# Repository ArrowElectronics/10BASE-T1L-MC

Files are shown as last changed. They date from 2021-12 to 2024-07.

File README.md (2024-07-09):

# 10BASE-T1L-MC: 10BASE-T1L to 10BASE-T Media Converter Platform 

This repository is dedicated to the 10BASE-T1L Media Converter including the source code, HW package files for Development, User Guides. 

The media converter (“10BASE-T1L-MC”) is a plug and play solution which enables seamlessly interfacing from single twisted pair (SPE) long reach Industrial Ethernet (“10BASET1L”)
to standard Ethernet (“10BASE-T”).

The 10BASE-T1L-MC is built using the industry leading PHY technology from Analog Devices ADI Chronous Family, namely the ADIN1100, 10BASE-T1L PHY and the ADIN1200, 10BASE-T PHY.

## 10BASE-T1L Software Package

The software package includes the configuration of both the PHY ADIN1100 and ADIN1200 with the MAX32660 MCU.

- Both the PHYs are configured with MCU over MDIO Interface GPIO Bit Banging.
- The PHYs has been programmmed to configure it in auto-negotiation, full-duplex mode, and speed at 10 Mbps. 
- The Device is programmmed with LED indication in case of various events like Power LED of MCU, Link Status LED and Activity Status LED for ADIN1100 and ADIN1200.  
- Debug UART hase been programmmed to show logs for Board Info and PHYs configuration status. 

## 10BASE-T1L Hardware Package

Hardware Package of 10BASE-T1L-MC contains Architectural Level Block Diagram, Gerber, BoM, Schematics for the development purpose, Pre-Scan Reports.

## 10BASE-T1L Mechanical Package

Mechanical Packages inlcudes CAD Data, Mechanical BoM, Mechanical Drawing, Packaging Instructions.

# Terms of Sale

Please refer to e-Infochips Private Limited Terms and Conditions of Sale found [here](https://uat.arrow.com/en/legal/terms-and-conditions-of-sale)

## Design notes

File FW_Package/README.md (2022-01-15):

# SW Pakcgage

The firmware released is of the Beta phase, it includes the development of ADIN1100 and ADIN1200 drivers, 
enabling the MDIO interface through GPIO Bit Banging, also the UART debugging through the debug console for the MCU Info, ADIN1100 and ADIN1200 debug log. 

## Software Tools Used

**Software Used**: [ ECLIPSE MAXIMSDK ](https://www.maximintegrated.com/en/design/software-description.html/swpart=SFW0010820A)<br/>
**Hardware Used**: Programming Cable (TC2030-IDC) and Programming Adapter – (MAX32625PICO#)

## Installation Notes

The installation manual followed for the development is as per the Programming Guide given for MAX32660 EVM Kit [(Programming_32660)](Programming_32660.pdf)  and following are the steps to be followed for debugging the device: 

1)	To open the given AIT1L project: page 14-19 in the above-mentioned document
2)	To build the project: Refer Page no. 6-7
3)	To debug the project: Refer Page no. 7-10
4)	To launch the UART debug console in serial terminal: 11-14

**Another way for flashing 10BASE-T1L without entering debugging mode:**

Tool used for flashing of device is Arm Toolchain and OpenOCD used to connect microcontrollers for debugging purpose. 

 To begin using OpenOCD, launch a command prompt window and change the directory to the location containing the application files you want to load. Load the file by running the following command line: 

[install_path]\Toolchain\bin\openocd -s [install_path]\Toolchain\share\openocd\scripts -f interface\[adapter].cfg -f target\[device].cfg -c "program [elf_file] verify exit"

Replace the parameters in [brackets] to match your configuration.
- [install_path]- This path where you installed the ARM toolchain. The default installation path is C:\Maxim
- [adapter] - The JTAG or SWD adapter connected to your board. In this case replace [adapter] --> cmsis-dap
- [device] - replace this with max32660
- [elf_file] - 10BASE-T1L-MC_B.elf

Command executed at development end:

C:\MaximTool\Toolchain\bin\openocd -s C:\MaximTool\Toolchain\share\openocd\scripts -f interface\cmsis-dap.cfg -f target\max32660.cfg -c "program AIT1L.elf verify exit" 

Note: Please follow the above replacements based on the installation path and project path at the individual end. 

Figure 8 shows an example for loading an AIT1L.elf to the device.

**Note**: Please follow the above replacements based on the installation path and project path at the individual end. 

Figure 8 shows an example for loading an AIT1L.elf to the device. 

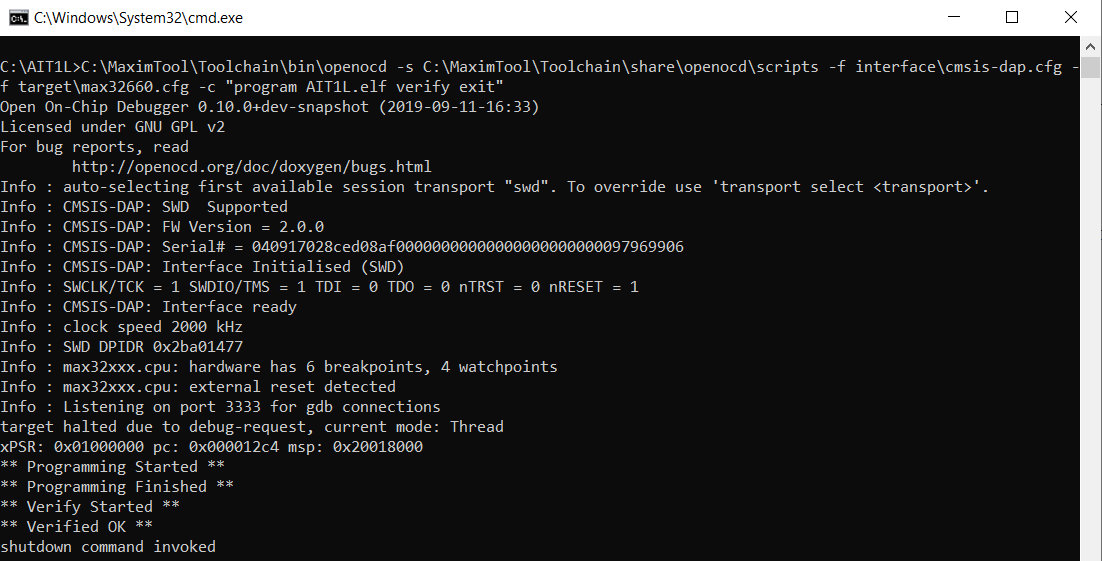
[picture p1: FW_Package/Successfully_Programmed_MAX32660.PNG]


Reference Web Link for Downloading the Software and all the steps for loading the program is shown below:

•	[How to Load Application to Maxim’s MAX32660 MCU](https://www.maximintegrated.com/en/design/technical-documents/app-notes/6/6973.html).

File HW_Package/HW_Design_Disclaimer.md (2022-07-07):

**DISCLAIMER**: THIS CIRCUIT DESIGN IS A PROVIDED AS REFERENCE ONLY, WITHOUT WARRANTY EXPRESSED OR IMPLIED.
THE USER IS ENCOURAGED TO PERFORM ALL DUE DILIGENCE WITH RESPECT TO DESIGN AND ANALYSIS.
FOR COMMITTED PERFORMANCE AND FUNCTIONALITY OF THE DEVICE, PLEASE REFER TO THE DEVICE DATA MANUAL

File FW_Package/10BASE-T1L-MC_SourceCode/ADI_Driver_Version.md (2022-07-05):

## ADIN1110 Driver (Non-OS) version information:

The ADIN1100 driver used at the time of development of 10BASE-T1L-MC is **adin1100_v1.0.0**.

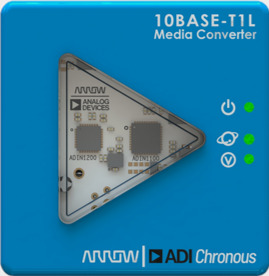
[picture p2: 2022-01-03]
Wiki_Page_Images/10BASE-T1L-MC.png

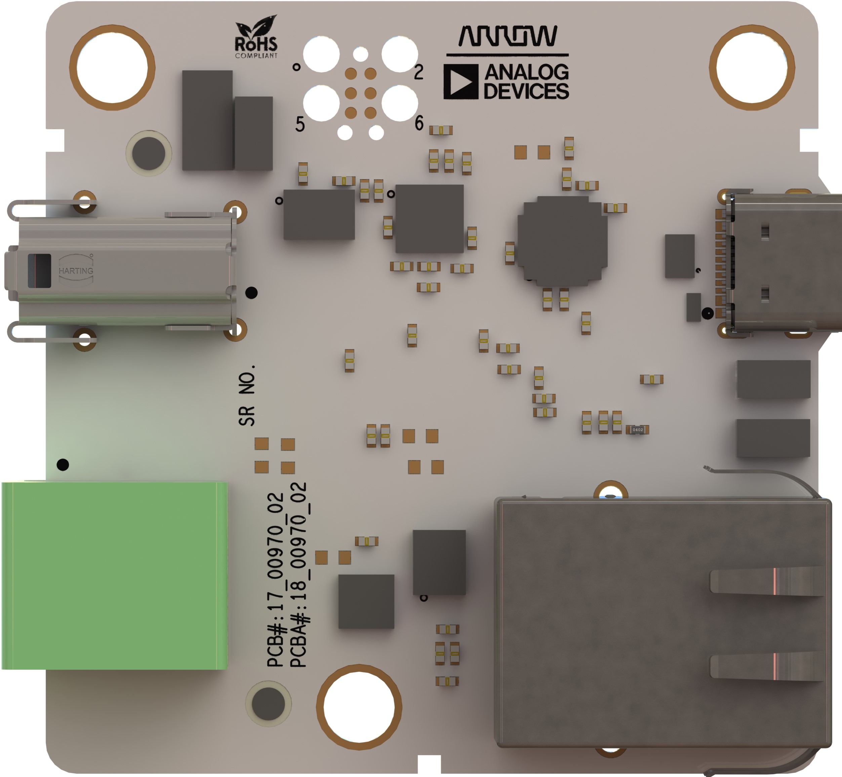
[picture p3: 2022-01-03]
Wiki_Page_Images/PCBA_FrontView.JPG

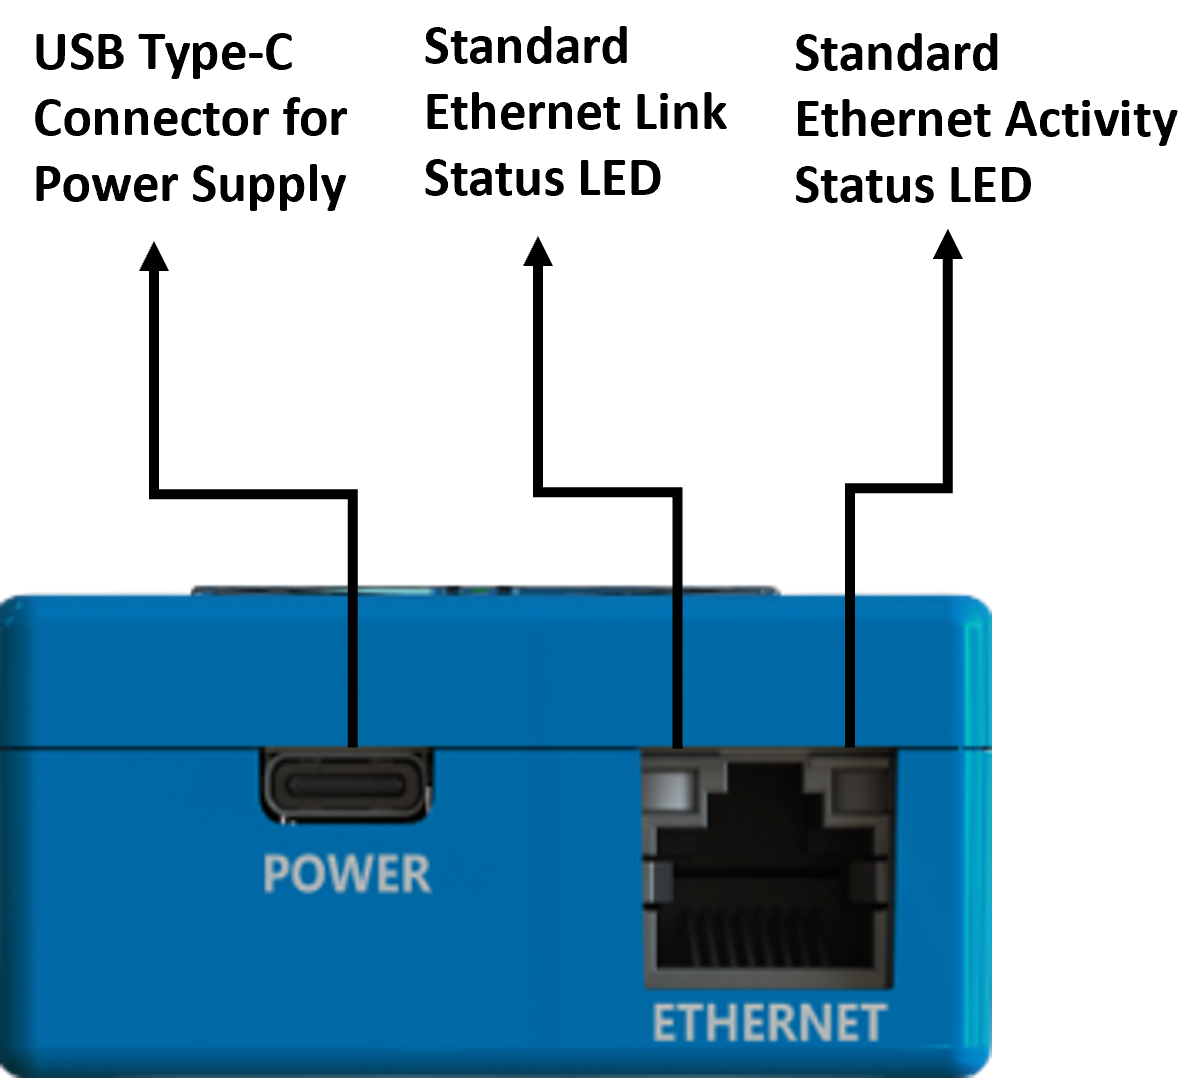
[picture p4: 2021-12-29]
Wiki_Page_Images/SideView_1.png

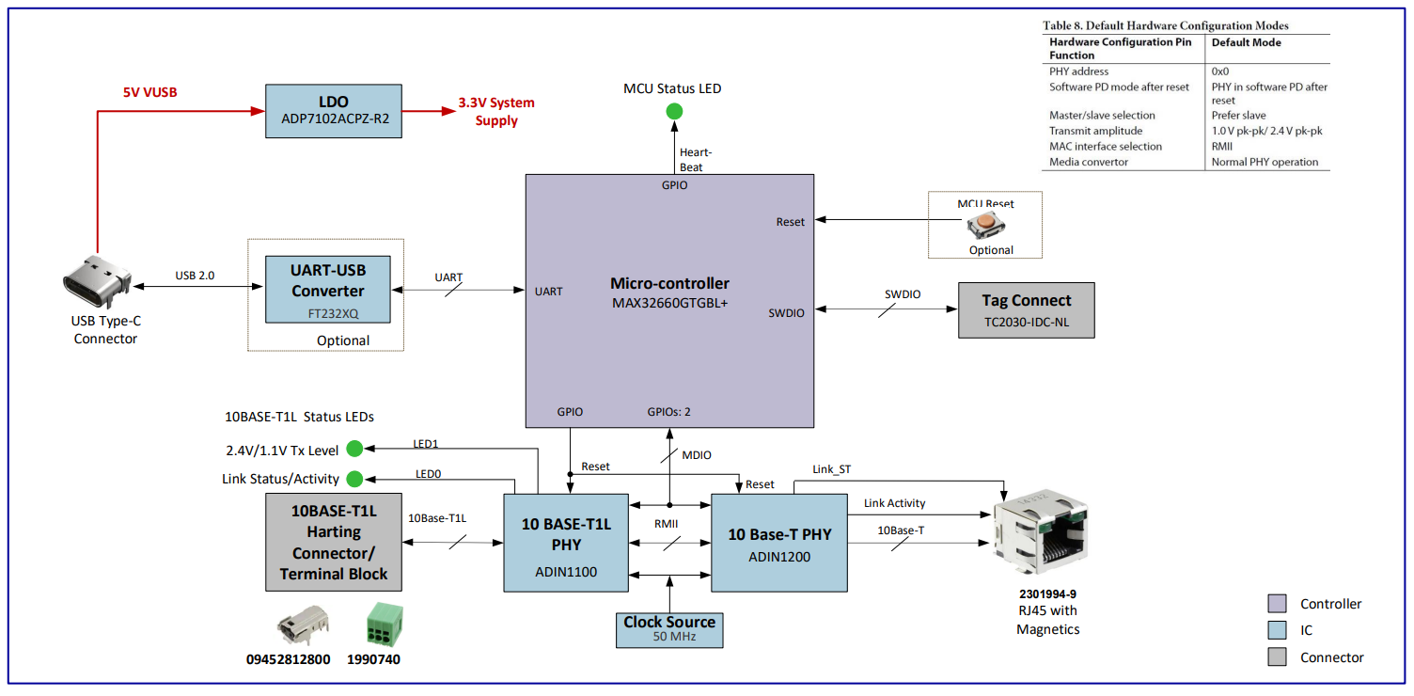
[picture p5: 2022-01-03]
Wiki_Page_Images/BlockDiagram.png

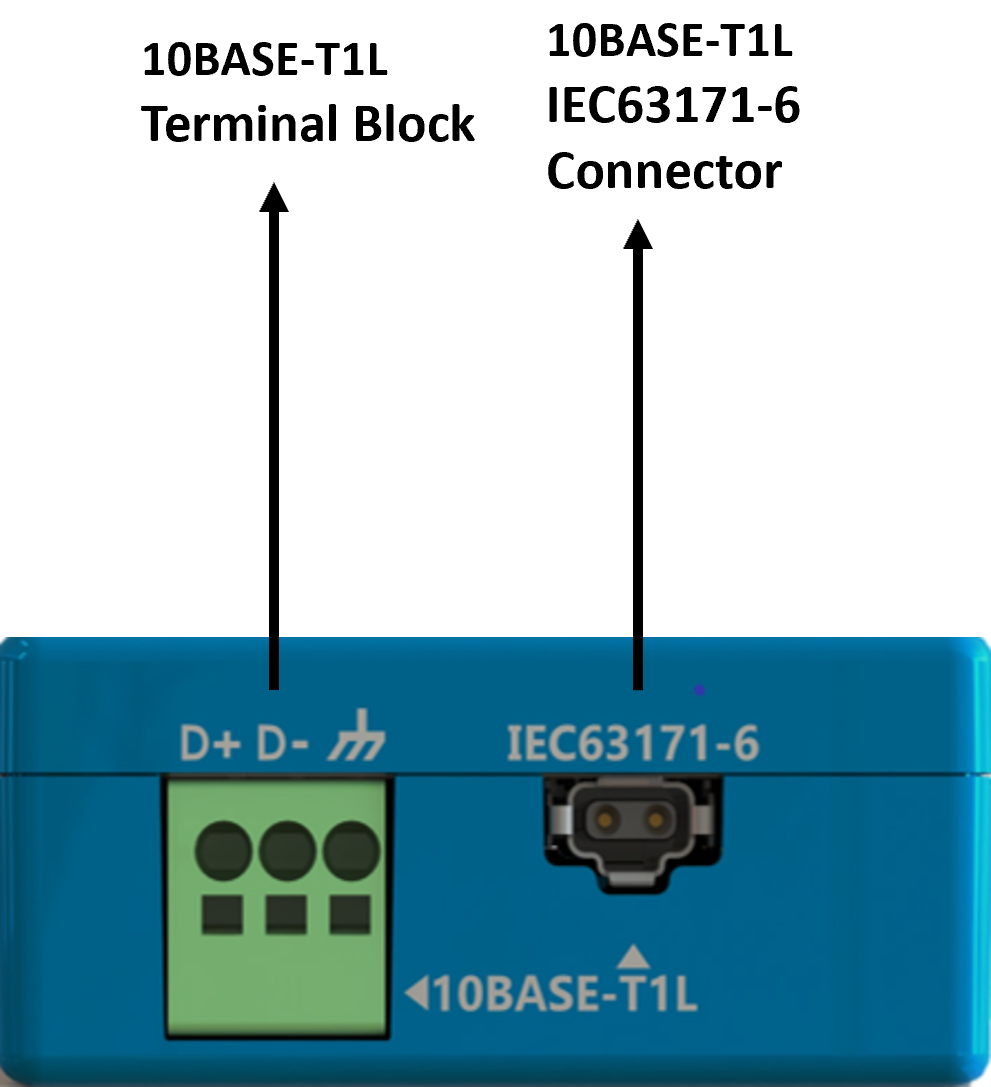
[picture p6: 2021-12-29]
Wiki_Page_Images/SideView_2.png

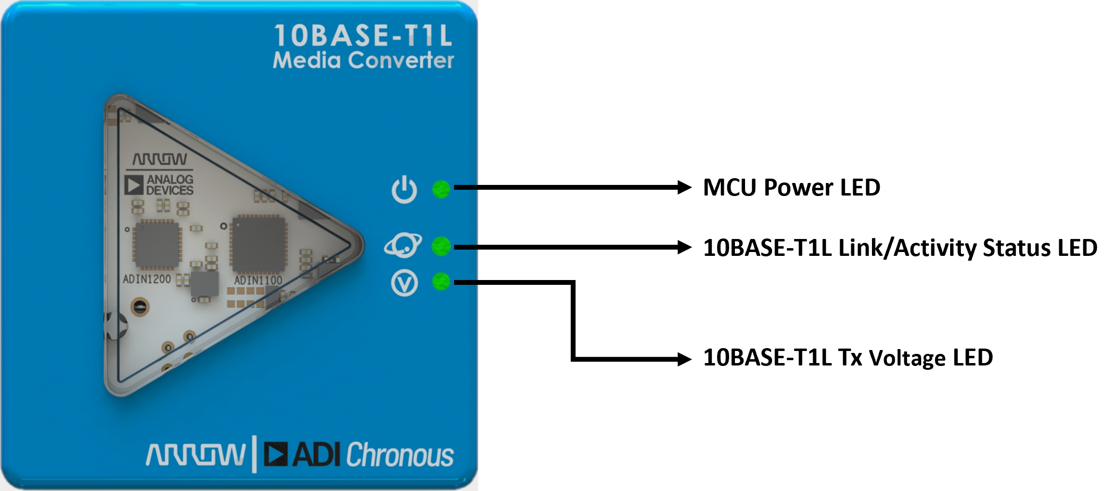
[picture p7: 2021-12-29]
Wiki_Page_Images/FrontView.png

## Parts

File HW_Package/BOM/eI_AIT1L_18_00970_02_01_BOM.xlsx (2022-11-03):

AIT1L Revised: Thurday, November 03, 2022
Revision: 3.0
Bill Of Materials Thurday, November 03, 2022 19:01:52
Item | Qty | Reference | Value | Mfg | Mfg_Part | Package | Operating_Temperature | RoHS | Mounting_Status | Specification | PCB Footprint | EOL | eI Part# | Updated EOL | Alt.1 Mfg# | Alt.1 Manufacturer | Alt.2 Mfg# | Alt.2 Manufacturer
1 | 2 | C1,C20 | 4.7uF | Yageo | CC0603KRX5R6BB475 | 603 | -55°C ~ 85°C | Yes |  | CAP CER 4.7UF 10V X5R 0603 | CAPC1608X90N_A_EINF | 7.3 years | 220000000000002347 |  | CL10A475KP8NNNC | Samsung Electro-Mechanics | CGB3B1X5R1A475K055AC | TDK Corporation
2 | 7 | C2,C17,C18,C38,C39,C49,C53 | 1uF | KEMET | C0402C105M4PAC7867 | 402 | -55°C ~ 85°C | Yes |  | CAP CER 1UF 16V X5R 0402 | RC0402 | 8.5 years | 220000000000000856 |  | CL05A105KO5NNNC | Samsung Electro-Mechanics | GRT155R61C105ME01D | Murata Electronics
3 | 1 | C3 | 2.2uF | Samsung Electro-Mechanics | CL10A225KP8NNNC | 603 | -55°C ~ 85°C | Yes |  | 2.2µF ±10% 10V Ceramic Capacitor X5R 0603 (1608 Metric) | RC0603 | 7.3 years | 220000000000002545 |  | CC0603KRX5R6BB225 | Yageo | CGA3E3X5R1A225K080AB | TDK Corporation
4 | 19 | C4,C12,C13,C14,C19,C22,C29,C30,C31,C32,C33,C34,C35,C36,C37,C46,C47,C55,C56 | 0.1uF | Samsung Electro-Mechanics | CL05B104KA5NNNC | 402 | -55°C ~ 125°C | Yes |  | CAP CER 0.1UF 25V X7R 0402 | RC0402 | 7.3 years | 220000000000000133 |  | CC0402KPX7R8BB104 | Yageo | GRM155R71E104KE14D | Murata Electronics
5 | 3 | C5,C44,C48 | 1000pF | AVX Corporation | 1206GC102KAT2A | 1206 | -55°C ~ 125°C | Yes |  | CAP CER 1000PF 2KV X7R 1206 | RC1206 | 13.4 years | 220000000000002393 |  | CL31B102KJHNNNE | Samsung Electro-Mechanics | C1206C102KGRACAUTO | KEMET
6 | 3 | C6,C7,C8 | 0.1uF | Samsung Electro-Mechanics | CL05B104KA5NNNC | 402 | -55°C ~ 125°C | Yes | DNP | CAP CER 0.1UF 25V X7R 0402 | RC0402 | 7.3 years | 220000000000000133 |  | CC0402KPX7R8BB104 | Yageo | GRM155R71E104KE14D | Murata Electronics
7 | 7 | C9,C10,C11,C25,C26,C27,C28 | 0.01uF | AVX Corporation | 0402YC103KAT2A | 402 | -55°C ~ 125°C | Yes |  | CAP CER 10000PF 16V X7R 0402 | RC0402 | 7.3 years | 220000000000004071 |  | CC0402KPX7R7BB103 | Yageo | CL05B103KO5NNWC | Samsung Electro-Mechanics
8 | 1 | C16 | 18pF | AVX Corporation | 04025A180JAT2A | 402 | -55°C ~ 125°C | Yes |  | CAP CER 18PF 50V C0G/NP0 0402 | RC0402 | 11.9 years | 220000000000004856 |  | CC0402JRNPO9BN180 | Yageo | CL05C180JB51PNC | Samsung Electro-Mechanics
9 | 1 | C21 | 10pF | TDK Corporation | CGA2B2NP01H100D050BA | 402 | -55°C ~ 150°C | Yes |  | CAP CER 10PF 50V NP0 0402 | RC0402 | 8.5 years | 220000000000004514 |  | CC0402DRNPO9BN100 | Yageo | CL05C100DB5NNNC | Samsung Electro-Mechanics
10 | 2 | C23,C24 | 0.22uF | KEMET | C0805C224K1RACTU | 805 | -55°C ~ 125°C | Yes |  | CAP CER 0.22UF 100V X7R 0805 | CAPC2012X140N_EINF | 8.5 years | 220000000000002883 |  | CC0805KKX7R0BB224 | Yageo | GRM21AR72A224KAC5L | Murata Electronics
11 | 2 | C42,C43 | 100pF | TDK Corporation | C3216X7S3D101K085AA | 1206 | -55°C ~ 125°C | Yes |  | CAP CER 100PF 2KV X7S 1206 | RC1206 | 8.5 years | 220000000000005713
12 | 1 | C50 | 47uF | Murata Electronics | GRM21BR61A476ME15L | 805 | 55°C ~ 85°C | Yes |  | CAP CER 47UF 10V X5R 0805 | RC0805 | 13.4 years | 220000000000001814 |  | GMC21X5R476M10NT | CAL-CHIP ELECTRONICS, INC.
13 | 1 | C57 | 2.7nF | YAGEO | CC0402KRX7R9BB272 | 402 | -55°C ~ 125°C | Yes | DNP | CAP CER 2700PF 50V X7R 0402 | RC0402 | 7.3 years | 220000000000003146 |  | C0402C272K5RAC7867 | KEMET | GCM155R71H272KA37D | Murata Electronics
14 | 3 | D1,D2,D3 | 150060VS75000 | Würth Elektronik | 150060VS75000 | 603 | -40°C ~ 85°C | Yes |  | Green 570nm LED Indication - Discrete 2V 0603 (1608 Metric) | LED_150060BS75000_EINF | 15 years | 310000000000001676 |  | 5988070107F | Dialight
15 | 1 | D4 | CDSOD323-T36SC | Bourns Inc. | CDSOD323-T36SC | SOD-323 | -55°C ~ 150°C | Yes |  | TVS DIODE 36VWM 75VC SOD323 | TVS_SOD-323 | 4.3 years | 230000000000002064 | >8 YEOL received over email from vendor
16 | 1 | D5 | CDSOD323-T24SC | Bourns Inc. | CDSOD323-T24SC | SOD-323 | -55°C ~ 150°C | Yes |  | TVS DIODE 24VWM 46.2VC SOD323 | TVS_SOD-323 | 4.3 years | 310000000000003053 | >8 YEOL received over email from vendor
17 | 1 | D6 | D5V0F1U2S9-7 | Diodes Incorporated | D5V0F1U2S9-7 | SOD-923 | -65°C ~ 155°C (Tj) | Yes |  | TVS DIODE 5.5VWM 12VC SOD923 | SOD-923 | 5.1 Years | 310000000000003134
18 | 4 | FB1,FB2,FB3,FB4 | 120E @100MHZ | Murata Electronics North America | BLM15PD121SN1D | 402 | -55°C ~ 125°C | Yes |  | FERRITE BEAD 120 OHM 0402 1LN | FB0402 | 6.4 years | 230000000000000191
19 | 1 | J1 | USB4105 | GCT | USB4105-GF-A |  | -40°C ~ 85°C | Yes |  | CONN RCP USB2.0 TYP C 24P SMD RA | GCT_USB4105-GF-A_EINF_1 | 7.5 years | 510000000000003696
20 | 1 | J2 | 09452812800 | HARTING | 09452812800 |  | -40°C ~ 85°C | Yes |  | CONN JACK 1PORT 1000 BASE-T1 PCB | HARTING_9452812800_EINF | 7.5 years | 510000000000003695
21 | 1 | J3 | 1990740 | Phoenix Contact | 1990740 | TH |  | Yes |  | TERM BLK 3POS SIDE ENT 3.5MM PCB | PHOENIX_1990740_EINF | 7.5 years | 510000000000003694
22 | 1 | J4 | 2301994-9 | TE Connectivity AMP Connectors | 2301994-9 |  | -40°C ~ 85°C | YES |  | CONN JACK 1PORT 100 BASE-T PCB | TI_2301994-9 | 15 years | 510000000000003812
23 | 1 | J5 | TC2030-IDC | Tag-Connect LLC | TC2030-IDC |  | -40°C ~ 105°C | Yes | DNP | Plug-Of-Nails™ Adapter Cable | tc2030-idc | 7.5 years | 510000000000003416
24 | 1 | L2 | 470uH | Würth Elektronik | 744242471 |  | -40°C ~ 125°C |  |  | CMC 470UH 400MA 2LN 2.2KOHM SMD | CHOKE_744242471 | 15 years | 230000000000002067
25 | 3 | MH1,MH2,MH3 | Mounting Hole |  |  |  |  | TBD |  |  | MTG459_561 |  | NA
26 | 1 | Q1 | BSS138 | ON Semiconductor | BSS138 | SOT-23-3 | -55°C ~ 150°C (TJ) | Yes |  | MOSFET N-CH 50V 220MA SOT23-3 | SOT23-3_ONSEMI | 6.4 years | 320000000000000082
27 | 1 | R1 | 22K | YAGEO | RC0603FR-0722KL | 603 | -55°C ~ 155°C | Yes |  | RES SMD 22K OHM 1% 1/10W 0603 | RC0603 | 7.3 years | 210000000000003569 |  | RC1608F223CS | Samsung Electro-Mechanics | CRGCQ0603F22K | TE Connectivity
28 | 2 | R3,R6 | 5.1K | Yageo | RC0402JR-075K1L | 402 | -55°C ~ 155°C | Yes | DNP | RES SMD 5.1K OHM 5% 1/16W 0402 | RC0402 | 11.7 years | 210000000000001012 |  | CR0402-16W-512JT | Venkel | RM04J512CT | CAL-CHIP ELECTRONICS, INC.
29 | 1 | R4 | 13K | Yageo | RC0402FR-0713KL | 402 | -55°C ~ 155°C | Yes |  | RES 13K OHM 1% 1/16W 0402 | RC0402 | 11.4 Years | 210000000000003662 |  | RM04F1302CT | CAL-CHIP ELECTRONICS, INC. | RMCF0402FT13K0 | Stackpole Electronics Inc
30 | 1 | R7 | 10K | Yageo | RC0402FR-0710KL | 402 | -55°C ~ 155°C | Yes | DNP | RES SMD 10K OHM 1% 1/16W 0402 | RC0402 | 11.7 years | 210000000000003292 |  | RC1005F103CS | Samsung Electro-Mechanics | CR0402-16W-1002FT | Venkel
31 | 2 | R8,R9 | 0E | Yageo | RC0402JR-070RL | 402 | -55°C ~ 155°C | Yes | DNP | RES SMD 0 OHM JUMPER 1/16W 0402 | RC0402 | 11.7 years | 210000000000000079 |  | RM04F0000CT | CAL-CHIP ELECTRONICS, INC. | CR0402-16W-000T | Venkel
32 | 5 | R10,R11,R42,R43,R46 | 470E | Yageo | RC0402FR-07470RP | 402 | -55°C ~ 155°C | Yes |  | RES SMD 470 OHM 1% 1/16W 0402 | RC0402 | 10.2 years | 210000000000002318 |  | CRGCQ0402F470R | TE Connectivity | CRCW0402470RFKEDC | Vishay Dale
33 | 5 | R16,R18,R63,R64,R73 | 4.7K | Yageo | RC0402JR-074K7L | 402 | -55°C ~ 155°C | Yes |  | RES SMD 4.7K OHM 5% 1/16W 0402 | RC0402 | 11.7 years | 210000000000000903 |  | RCG04024K70JNED | Vishay Dale | CRGCQ0402J4K7 | TE Connectivity
34 | 2 | R25,R30 | 49.9E | Yageo | RT0603FRE0749R9L | 603 | -55°C ~ 155°C | Yes |  | RES SMD 49.9 OHM 1% 1/10W 0603 | RC0603 | 7.3 years | 210000000000001073 |  | CRCW060349R9FKEAC | Vishay Dale | RC1608F49R9CS | Samsung Electro-Mechanics
35 | 2 | R26,R29 | 4.99K | Yageo | RC0603FR-074K99L | 603 | -55°C ~ 155°C | Yes |  | RES SMD 4.99K OHM 1% 1/10W 0603 | RC0603 | 7.3 years | 210000000000001645 |  | CRCW06034K99FKEA | Vishay Dale | RC1608F4991CS | Samsung Electro-Mechanics
36 | 5 | R27,R28,R47,R48,R66 | 10K | Yageo | RT0603FRE0710KL | 603 | -55°C ~ 155°C | Yes |  | RES SMD 10K OHM 1% 1/10W 0603 | RC0603 | 7.3 years | 210000000000001097 |  | CRCW060310K0FKEAC | Vishay Dale | CRGCQ0603F10K | TE Connectivity
37 | 5 | R33,R34,R35,R36,R58 | 10K | Yageo | RC0402FR-0710KL | 402 | -55°C ~ 155°C | Yes |  | RES SMD 10K OHM 1% 1/16W 0402 | RC0402 | 11.7 years | 210000000000003292 |  | RC1005F103CS | Samsung Electro-Mechanics | CR0402-16W-1002FT | Venkel
38 | 1 | R39 | 56K | Yageo | AF0402FR-0756KL | 402 | -55°C ~ 155°C | Yes |  | RES SMD 56K OHM 1% 1/16W 0402 | RC0402 | 7.3 years | 210000000000003774 |  | CR0402-16W-5602FT | Venkel | RM04F5602CT | Venkel
39 | 3 | R40,R71,R72 | 22E | Yageo | RC0402JR-0722RL | 402 | -55°C ~ 155°C | Yes |  | RES SMD 22 OHM 5% 1/16W 0402 | RC0402 | 7.3 years | 210000000000001283 |  | CRCW040222R0JNEDC | Vishay Dale | RCS1005J220CS | Samsung Electro-Mechanics
40 | 1 | R41 | 3.01K | Yageo | AC0402FR-073K01L | 402 | -55°C ~ 155°C | Yes |  | RES SMD 3.01K OHM 1% 1/16W 0402 | RC0402 | 7.3 years | 210000000000003963 |  | CR0402-16W-3011FT | Venkel | RM04F3011CT | CAL-CHIP ELECTRONICS, INC.
41 | 1 | R44 | 1.5K | Yageo | RC0402JR-071K5L | 402 | -55°C ~ 155°C | Yes |  | RES SMD 1.5K OHM 5% 1/16W 0402 | RC0402 | 11.7 years | 210000000000001431 |  | CRGCQ0402J1K5 | TE Connectivity | RM04J152CT | CAL-CHIP ELECTRONICS, INC.
42 | 3 | R45,R60,R62 | 0E | Yageo | RC0402JR-070RL | 402 | -55°C ~ 155°C | Yes |  | RES SMD 0 OHM JUMPER 1/16W 0402 | RC0402 | 11.7 years | 210000000000000079 |  | RM04F0000CT | CAL-CHIP ELECTRONICS, INC. | CR0402-16W-000T | Venkel
43 | 2 | R49,R57 | 4.7M | Panasonic Electronic Components | ERJ-12ZYJ475U | 603 | -55°C ~ 155°C | Yes |  | RES SMD 4.7M OHM 5% 3/4W 2010 | RESC5025X70N_EINF | 7.3 years | 210000000000005063 |  | CRGCQ2010J4M7 | TE Connectivity
44 | 3 | R50,R51,R54 | 100K | Vishay Beyschlag/Draloric/BC Components | MCS04020C1003FE000 | 402 | -55°C ~ 155°C | Yes |  | RES SMD 100K OHM 1% 1/10W 0402 | RC0402 | 11.7 years | 210000000000001337 |  | CR0402-10W-1003FT | Venkel | ERJ-U02F1003X | Panasonic Electronic Components
45 | 3 | R59,R67,R68 | 100E | Vishay Dale | CRCW0402100RFKEE | 402 | -55°C ~ 155°C | Yes |  | RES SMD 100 OHM 1% 1/16W 0402 | RC0402 | 7.3 years | 210000000000003752 |  | RC0402FR-07100RP | Yageo | CRG0402F100R | TE Connectivity
46 | 1 | R61 | 56K | Yageo | AF0402FR-0756KL | 402 | -55°C ~ 155°C | Yes | DNP | RES SMD 56K OHM 1% 1/16W 0402 | RC0402 | 7.3 years | 210000000000003774 |  | CR0402-16W-5602FT | Venkel | RM04F5602CT | Venkel
47 | 2 | R69,R70 | 4.7K | Yageo | RC0402JR-074K7L | 402 | -55°C ~ 155°C | Yes | DNP | RES SMD 4.7K OHM 5% 1/16W 0402 | RC0402 | 11.7 years | 210000000000000903 |  | CR0402-16W-472JT | Venkel | RM04J472CT | CAL-CHIP ELECTRONICS, INC.
48 | 1 | SW1 | PTS830GM140 SMTR LFS | C&K | PTS830GM140 SMTR LFS |  | -40°C ~ 85°C | Yes | DNP | SWITCH TACTILE SPST-NO 0.05A 12V | SW_PTS830GM140G | 9 years | 540000000000001195
49 | 1 | U1 | ADIN1100BCPZ-R7 | Analog Devices Inc. | ADIN1100BCPZ-R7 | 40-LFCSP (6x6) | -40°C ~ 85°C | Yes |  | 10BASE-T1L PHY WITH 4 MDI | QFN40_50P600X600_08H | 10 years | 700000000000006074
50 | 1 | U2 | ADIN1200BCP32Z | Analog Devices | ADIN1200BCP32Z | 32-LFCSP | -40°C ~ 85°C (TA) | Yes |  | 4/4 Transceiver Full, Half Ethernet, IEEE 802.3, MII, RMII, PHY2 32-LFCSP (5x5) | lfcsp_32p_5x5mm | 10 years | 700000000000006075
51 | 1 | U3 | ADP7102ACPZ-R7 | Analog Devices Inc. | ADP7102ACPZ-R7 | LFCSP | -55°C ~ 125°C | Yes |  | IC REG LIN POS ADJ 300MA 8LFCSP | 8-LFCSP-WD_3x3mm | 10 years | 700000000000006912
52 | 1 | U4 | MAX32660GTGBL+ | Maxim Integrated | MAX32660GTGBL+ | 24-TQFN (3x3) | -40°C ~ 105°C (TA) | Yes |  | IC MCU 32BIT 256KB FLASH 24TQFN | 24TQFN_3x3-Maxim |  | 700000000000006684
53 | 1 | U5 | FT230XQ-R | FTDI | FT230XQ-R | 16QFN_4x4_FTDI | -40°C ~ 85°C | Yes | DNP | IC USB SERIAL BASIC UART 16QFN | QFN65P400x400_16_PWP | 6 years | 700000000000001480
54 | 2 | U6,U9 | DT1042-04SO-7 | Diodes Incorporated | DT1042-04SO-7 | SOT-23-6 | -40°C ~ 125°C (TJ) | Yes |  | TVS DIODE 5VWM 9VC SOT26 | SOT23-6 | 5.1 years | 310000000000003035
55 | 1 | U7 | ECMF02-4CMX8 | STMicroelectronics | ECMF02-4CMX8 | 8-UFDFN | -40°C ~ 125°C | Yes | DNP | COMMON MODE CHOKE 2LN SMD ESD | fil_ecmf02-4cmx8 | 4.3 years | 230000000000001192 | NO EOL plan for next 10 Years. Received over email
56 | 1 | Y1 | ECS-2520MV-500-CN-TR | ECS Inc. | ECS-2520MV-500-CN-TR | 4-SMD, No Lead | -40°C ~ 85°C | Yes |  | XTAL OSC XO 50.0000MHZ CMOS SMD | OSCCC200X250X90-4N_A | 6 years | 410000000000000529
57 | 1 | 17_00970_03 | 17_00970_03 | eInfochips | Bare PCB 3.0 |  |  |  |  | PCB AIT1L MEDIA CONVERTER DONGLE REV 3.0 |  | NA | 170000000000001274
 | DISCLAIMER: THIS CIRCUIT DESIGN IS A PROVIDED AS REFERENCE ONLY, WITHOUT WARRANTY EXPRESSED OR IMPLIED. THE USER IS ENCOURAGED TO PERFORM ALL DUE DILIGENCE WITH RESPECT TO DESIGN AND ANALYSIS. FOR COMMITTED PERFORMANCE AND FUNCTIONALITY OF THE DEVICE, PLEASE REFER TO THE DEVICE DATA MANUAL.

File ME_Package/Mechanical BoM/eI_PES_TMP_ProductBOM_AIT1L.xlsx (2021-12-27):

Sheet: Intro
Product Bill of Material
ADCOE_Industry_4.0_10BaseT1L
Confidentiality Notice Copyright (c) 2021 eInfochips. - All rights reserved This document is authored by eInfochips and is eInfochips intellectual property, including the copyrights in all countries in the world. This document is provided under a license to use only with all other rights, including ownership rights, being retained by eInfochips. This file may not be distributed, copied, or reproduced in any manner, electronic or otherwise, without the express written consent of eInfochips. Template Version 1.3

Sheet: Document Detail
Document History
Version | Author |  | Reviewer |  | Approver
 | Name | Date (DD-MMM-YYYY) | Name | Date (DD-MMM-YYYY) | Name | Date (DD-MMM-YYYY) | *Note: <The details written into document history should be deleted and updated according to project requirements.>
0.1 | Sanket Radde | 17-06-2021 | Akshay Ballal | 17-06-2021 | Kishor Bankar | 18-06-2021
Version | Description Of Changes
Definition/ Acronym/ Abbreviation
BOM | Bill of Material
DM | Delivery Manager
EI | eInfochips Ltd
MOC | Material of Construction
References
S.No | Document |  | Version | Remarks

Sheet: List of Items
Product Bill-of-Material
Project Name |  | AIT1L
Product Name |  | WiFi Dongle
Product Part#
Revision of the BOM |  | 0.1
 |  |  |  |  |  |  | <<Add columns if required>>
Sr # | Part Description | Manufacturer | Manufacturer Part# | Distributor | eI part# | Quantity | Remarks
1 | TOP ENCLOSURE – AIT1L | EIC | NA |  | 21_00931_01 | 1
2 | BOTTOM ENCLOSURE - AIT1L | EIC | NA |  | 21_00932_01 | 1
3 | PCBA_AIT1L | EIC | NA |  | 21_00949_01 | 1
4 | LIGHT PIPE GUIDE - AIT1L | BIVAR | PLPC2-188 |  | NA | 3
5 | HEAT SET INSERT_M2 | MCMASTER | 94459A120 |  | NA | 3
6 | M2X6_ 18-8 SS PAN HEAD PHILLIPS SCREWS | MCMASTER | 92000A013 |  | NA | 3
 |  |  |  |  |  |  | Note: Provide reference sheet for PCA and Mechanical assembly BOM

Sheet: BOM - Mech
# | Description of Component | EI Part Number | Part Type | Manufacturer | Manufacturer Part Number | Material Type | Specification (i.e. Dimension; Temp; Certification; Standard) | Unit of Measure (i.e. Nos) | Required Quantity | Lead Time | Unit Cost (Optional) | Total Cost (Optional) | 3D Model | DFM / DFA | Reference Document / Drawing | Alternate Manufacturer / Supplier (Optional) | Remarks
1 | TOP ENCLOSURE – AIT1L | 21_00931_01 | CUSTOM | EIC | NA | PC |  |  | 1
2 | BOTTOM ENCLOSURE - AIT1L | 21_00932_01 | CUSTOM | EIC | NA | ABS |  |  | 1
3 | PCBA_AIT1L | 21_00949_01 | CUSTOM | EIC | NA | FR4 |  |  | 1
4 | LIGHT PIPE GUIDE - AIT1L | NA | STANDARD | BIVAR | PLPC2-188 | PC |  |  | 3
5 | HEAT SET INSERT_M2 | NA | STANDARD | MCMASTER | 94459A120 | BRASS |  |  | 3
6 | M2X6_ 18-8 SS PAN HEAD PHILLIPS SCREWS | NA | STANDARD | MCMASTER | 92000A013 | 18-8 SS |  |  | 3
7
8
9
10
 | Note: If there is any critical component listed in above table, highlight that particular row of critical component.
 | << This is Optional sheet, If project is not using any tool generated BOM>>

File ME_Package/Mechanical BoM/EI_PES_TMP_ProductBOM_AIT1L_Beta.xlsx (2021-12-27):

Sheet: Intro
 | Template Version 1.1
Bill of Material
ADCOE_Industry_4.0_10BaseT1L
Confidentiality Notice Copyright (c) 2019 eInfochips. - All rights reserved This document is authored by eInfochips and is eInfochips intellectual property, including the copyrights in all countries in the world. This document is provided under a license to use only with all other rights, including ownership rights, being retained by eInfochips. This file may not be distributed, copied, or reproduced in any manner, electronic or otherwise, without the express written consent of eInfochips.

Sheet: Document Detail
Document History
Version | Author |  | Reviewer |  | Approver
 | Name | Date (DD-MMM-YYYY) | Name | Date (DD-MMM-YYYY) | Name | Date (DD-MMM-YYYY) | *Note: <The details written into document history should be deleted and updated according to project requirements.>
Draft 0.1 | Sanket Radde | 2021-08-30 | Akshay Ballal | 2021-08-30 | Kishor Bankar | 2021-09-01
Version | Description Of Changes
Draft 0.1 | First Draft
Baseline 1.0 | Final BoM Beta
Definition/ Acronym/ Abbreviation
BOM | Bill of Material
DM | Delivery Manager
EI | eInfochips Ltd
MOC | Material of Construction
References
S.No | Document |  | Version | Remarks

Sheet: List of Items
Product Bill-of-Material
Project Name |  | ADCOE_Industry_4.0_10BaseT1L
Product Name |  | WiFi Dongle
Product Part#
Revision of the BOM |  | Baseline 1.0
 |  |  |  |  |  |  | <<Add columns if required>>
Sr # | Part Description | Manufacturer | Manufacturer Part# | Distributor | eI part# | Quantity | Remarks
1 | AIT1L ASSEMBLY | CUSTOM (MECH.) |  | NA | 21_01019_01 | 1 | None
2 | TOP ENCLOSURE ASSEMBLY_AIT1L | CUSTOM (MECH.) |  | NA | 21_01020_01 | 1 | None
3 | TOP ENCLOSURE WITH INSERTS_AIT1L | CUSTOM (MECH.) |  | NA | 21_01021_01 | 1 | None
4 | TOP ENCLOSURE_AIT1L_REV2 | CUSTOM (MECH.) |  | NA | 21_00931_02 | 1 | None
5 | WINDOW_TOP COVER | CUSTOM (MECH.) |  | NA | 21_01018_01 | 1 | None
6 | M2_HEAT SET INSERTS | McMasterr | 94459A120 | McMasterr | NA | 3 | None
7 | PCBA_AIT1L | CUSTOM (HW) |  | NA | 21_00949_02 | 1 | None
8 | LIGHT GUIDE PIPE | BIVAR | PLPC2-188 | Mouser | NA | 3 | None
9 | BOTTOM ENCLOSURE_AIT1L_REV2 | CUSTOM(MECH.) |  | NA | 21_00932_02 | 1 | None
10 | M2X6_PAN HEAD PHILLIPS SCREW | McMasterr | 92000A013 | McMasterr | NA | 3 | None

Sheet: List of Items - Multi Level BoM
Sr.No | Level |  |  |  |  | Einfochips Part No. | Part Description | Qty. / Unit | Type | Vendor | Vendor Part No. | MOQ | Price / MOQ (USD) | Material | Vendor Link | Document Link | Remarks
 | 1 | 2 | 3 | 4 | 5
1 | 1 |  |  |  |  | 21_01019_01 | AIT1L ASSEMBLY | 1 | MAKE | CUSTOM (MECH.) |  | 1 |  | NA |  |  | Top Level Assembly
2 |  | 2 |  |  |  | 21_01020_01 | TOP ENCLOSURE ASSEMBLY_AIT1L | 1 | MAKE | CUSTOM (MECH.) |  | 1 |  | NA
3 |  |  | 3 |  |  | 21_01021_01 | TOP ENCLOSURE WITH INSERTS_AIT1L | 1 | MAKE | CUSTOM (MECH.) |  | 1 |  | NA
4 |  |  |  | 4 |  | 21_00931_02 | TOP ENCLOSURE_AIT1L_REV2 | 1 | MAKE | CUSTOM (MECH.) |  | 1 |  | ABS
5 |  |  |  | 4 |  | 21_01018_01 | WINDOW_TOP COVER | 1 | MAKE | CUSTOM (MECH.) |  | 1 |  | PC
6 |  |  |  | 4 |  | NA | M2_HEAT SET INSERTS | 3 | BUY | McMasterr | 94459A120 | 50 |  | BRASS | https://www.mcmaster.com/94459A120/
7 |  |  | 3 |  |  | 21_00949_02 | PCBA_AITAL | 1 | MAKE | CUSTOM (HW) |  | 1 |  | FR4 |  |  | Part of HW BoM
8 |  |  | 3 |  |  | NA | LIGHT GUIDE PIPE | 3 | BUY | BIVAR | PLPC2-188 | 1 |  | PC | https://www.mouser.in/ProductDetail/Bivar/PLPC2-188?qs=bY1dm4K8r4XM%2FGDckgCPZw==
9 |  | 2 |  |  |  | 21_00932_02 | BOTTOM ENCLOSURE_AIT1L_REV2 | 1 | MAKE | CUSTOM(MECH.) |  | 1 |  | ABS
10 |  | 2 |  |  |  | NA | M2X6_PAN HEAD PHILLIPS SCREW | 3 | BUY | McMasterr | 92000A013 | 100 |  | 18-8 SS | https://www.mcmaster.com/92000A013/

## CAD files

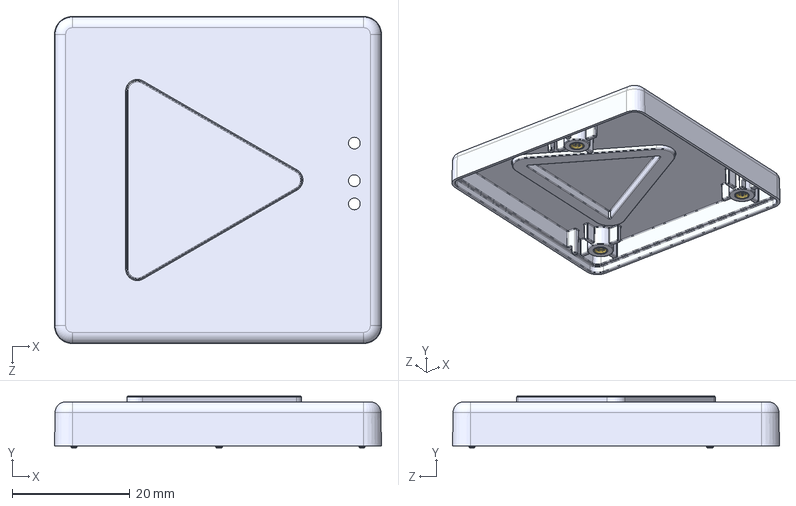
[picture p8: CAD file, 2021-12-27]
ME_Package/CAD Data/ASSEMBLY OF INSERTS & ULTRASONIC WELDING/TOP ENCLOSURE WITH INSERTS_AIT1L.STEP
55.7 x 8.85 x 55.7 mm
TOP ENCLOSURE
94459A120_BRASS HEAT-SET INSERT FOR PLASTIC (1)_94459A120 x 3
WINDOW_TOP COVER

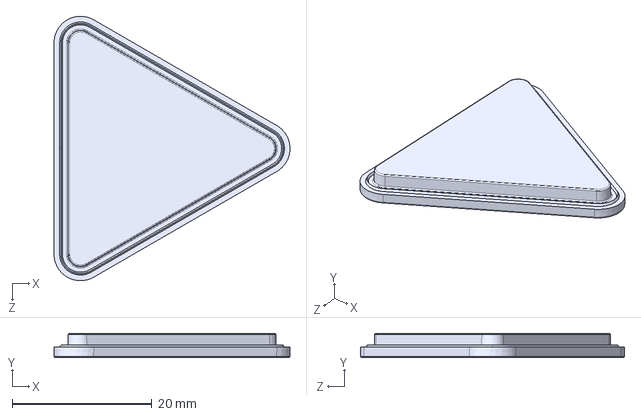
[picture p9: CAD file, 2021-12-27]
ME_Package/CAD Data/PARTS/WINDOW_TOP COVER.STEP
33.8 x 3.50 x 37.9 mm

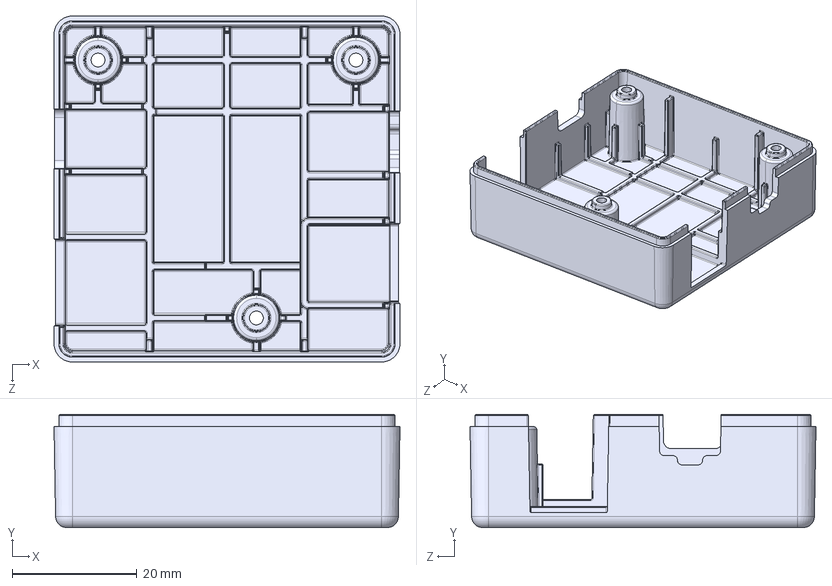
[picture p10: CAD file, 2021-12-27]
ME_Package/CAD Data/PARTS/BOTTOM ENCLOSURE.STEP
55.5 x 18.2 x 55.5 mm

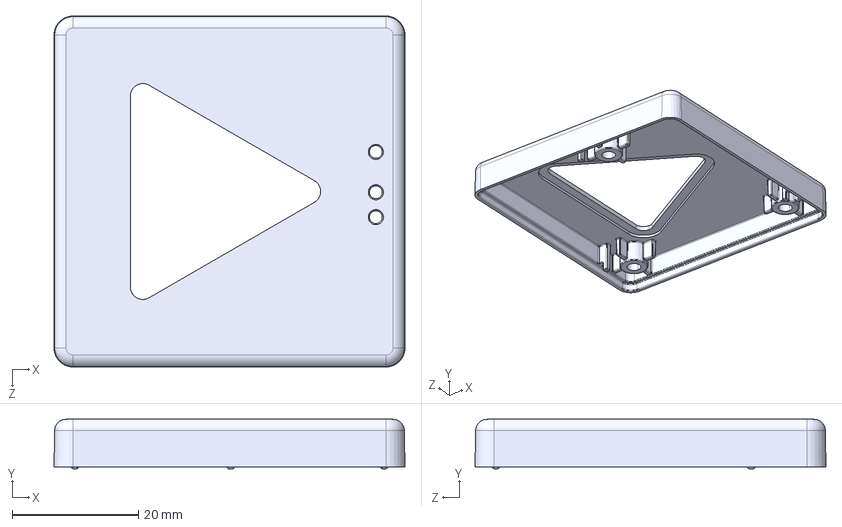
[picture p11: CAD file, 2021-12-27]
ME_Package/CAD Data/PARTS/TOP ENCLOSURE.STEP
55.7 x 7.85 x 55.7 mm

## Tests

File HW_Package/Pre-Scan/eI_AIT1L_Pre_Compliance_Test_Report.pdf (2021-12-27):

Regulatory EMI Test Report | eInfochips Ltd. Confidential | Page 1 of 10

# CISPR Pre-Compliance Test Report

# AIT1L

Version
Status
Date

1.0
Baselined
21-Dec-2021

Confidentiality Notice
Copyright © 2021 eInfochips. – All rights reserved

Template Version: 1.3

Regulatory EMI Test Report | eInfochips Ltd. Confidential | Page 2 of 10

This document is authored by eInfochips and is eInfochips intellectual property, including the copyrights in all countries in the world. This document is provided under a license to use only with all other rights, including ownership rights, being retained by eInfochips. This file may not be distributed, copied, or reproduced in any manner, electronic or otherwise, without the express written consent of eInfochips.

## CONTENTS

Regulatory EMI Test Report | eInfochips Ltd. Confidential | Page 3 of 10

## FIGURES

Figure 1: AIT1L Test Setup Block Diagram | 5
Figure 2: Test Set-up in Anechoic Chamber | 6
Figure 3: Test Waveform- Horizontal Scan | 8
Figure 4: Test Result- Vertical Scan | 9

## TABLES

Table 1 : Document History | 4
Table 2 : Change Description | 4
Table 3 : Acronyms & Abbreviations | 4
Table 4 : References | 4
Table 5: Radiated Emission Limit Class-A | 5
Table 6: Radiated Emission Limit Class-B optional | 5
Table 7: Test Results | 7

Regulatory EMI Test Report | eInfochips Ltd. Confidential | Page 4 of 10

## 1 DOCUMENT DETAILS

### 1.1 Document History

Version | Author | Reviewer | Approver
Name | Date (DD-MM-YYYY) | Name | Date (DD-MMM-YYYY) | Name | Date (DD-MM-YYYY)
Rev 0.1 | Hiren Patel | 23-Nov-2021 | Mahesh Gohil | 23-Nov-2021
Baselined 1.0 | Hiren Patel | 20-Dec-2021 | Mahesh Gohil | 21-Dec-2021 | Kalpesh Balar | 21-Dec-2021

Table 1 : Document History

Version | Description of Change
Rev 0.1 | First Draft created.
Baselined 1.0 | Test Result updated in draft 0.2 after testing. Rev 0.2 is baselined after internal review.

Table 2 : Change Description

### 1.2 Definition, Acronyms and Abbreviation

Definition/ Acronym/ Abbreviation | Description
dBuV/m | Decibel-microvolt per meter
EMI | Electromagnetic Interference
CISPR | International Special Committee on Radio Interference
RE | Radiated Emission

Table 3 : Acronyms & Abbreviations

### 1.3 References

# | Document | Version | Remarks

Table 4 : References

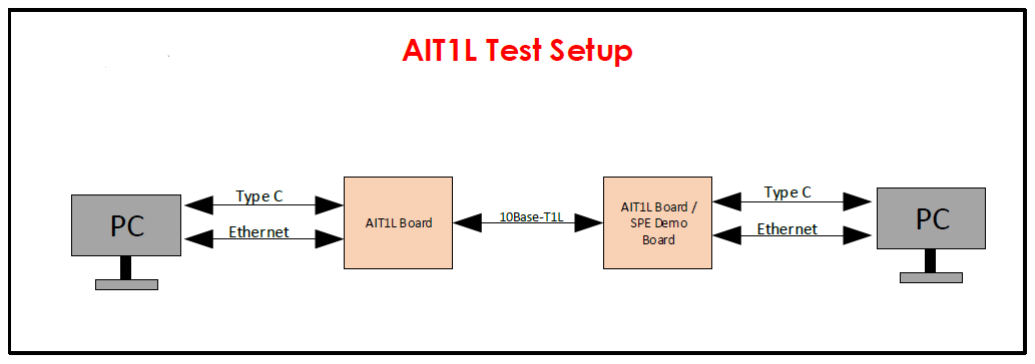
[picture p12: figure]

Regulatory EMI Test Report | eInfochips Ltd. Confidential | Page 5 of 10

## 2 REGULATORY VERIFICATION REQUIREMENT

### 2.1 Radiated Emission Test

### 2.1.1 Purpose

To test AIT1L device for Radiated Emissions for the CISPR part 22 class A limits

CISPR Requirements:
The EUT shall be tested as per CISPR-22 class-A Radiated emission specifications and emission shall not exceed the specifications given below.
Frequency Range (MHz) | Limit (dBuV/m) @ 3m distance | Limit (dBuV/m) @ 10m distance
30-230 | 50 | 40
230-1000 | 57 | 47

Table 5: Radiated Emission Limit Class-A

Frequency Range (MHz) | Limit (dBuV/m) @ 3m distance | Limit (dBuV/m) @ 10m distance
30-230 | 40 | 30
230-1000 | 47 | 37

Table 6: Radiated Emission Limit Class-B optional

### 2.1.2 Setup

Test setup requirement is as below,

a) Test equipment as per the RE standard
b) AIT1L devices- (2 pcbs)
c) Type-C to Type-A USB cable – (2 nos)
d) Ethernet straight/cross cable – to connect with Linux Laptop (2 nos)
e) 10Base T1L Harting cable (0.5m) – to connect 2 boards back-to-back
f) Linux Test Laptop – (2 nos)

Figure 1: AIT1L Test Setup Block Diagram

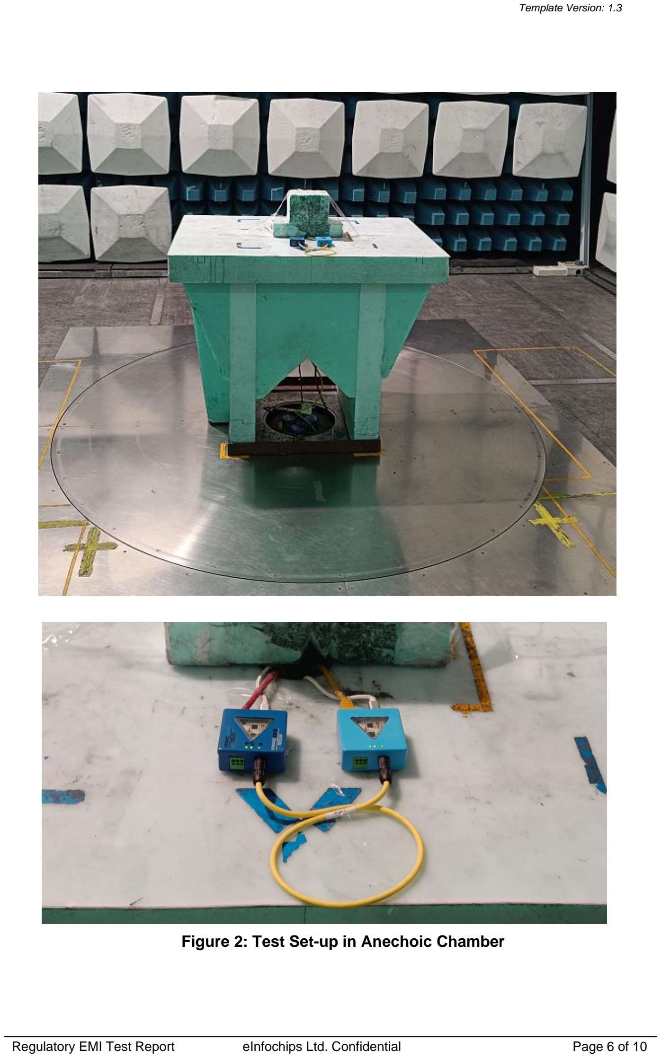
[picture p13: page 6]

Regulatory EMI Test Report | eInfochips Ltd. Confidential | Page 6 of 10

### Figure 2: Test Set-up in Anechoic Chamber

Regulatory EMI Test Report | eInfochips Ltd. Confidential | Page 7 of 10

### 2.1.3 Test Procedure

1. Connect the two AIT1L boards back-to-back using 10BaseT1L cable on Harting connectors.
2. Connect ethernet port of each AIT1L device with test laptops.
3. Connect Type-C USB port of each device with test laptops to power on the device.
4. Assign static IP address to both the test laptops.
5. Run iperf3 client/server command on both laptops.
6. Both the devices are required to be on turn the table.
7. Add the limit line in spectrum for class A and Class B.
8. Perform the scan from 30Mhz to 1GHz to see emissions from the EUT if any for both polarizations of antenna.
9. Note down the frequencies, which have high emissions.

### 2.1.4 Acceptance criteria

All the Radiated emissions generated by the EUT shall have a 5dB margin from limits specified above for CISPR-22 verifications.

### 2.1.5 Test Cases

Waveform# | Test Condition | Test Set up | Observation | Scan | Pass/Fail
1 | 30Mhz - 1Ghz | 10BaseT1L communication over Harting connector. | - | Full Scan | Pass

Table 7: Test Results

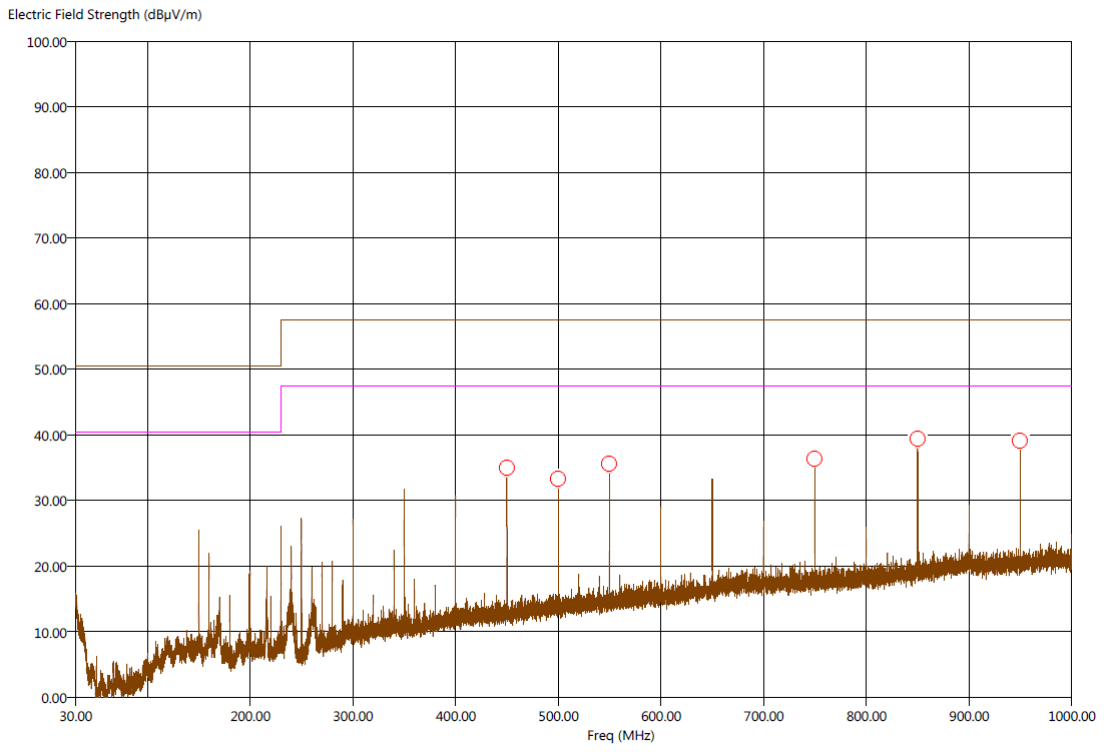
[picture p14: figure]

Regulatory EMI Test Report | eInfochips Ltd. Confidential | Page 8 of 10

### 2.1.6 Test waveform: Test with Single Pair Haring Cable at 10Base T1L Port

Figure 3: Test Waveform- Horizontal Scan

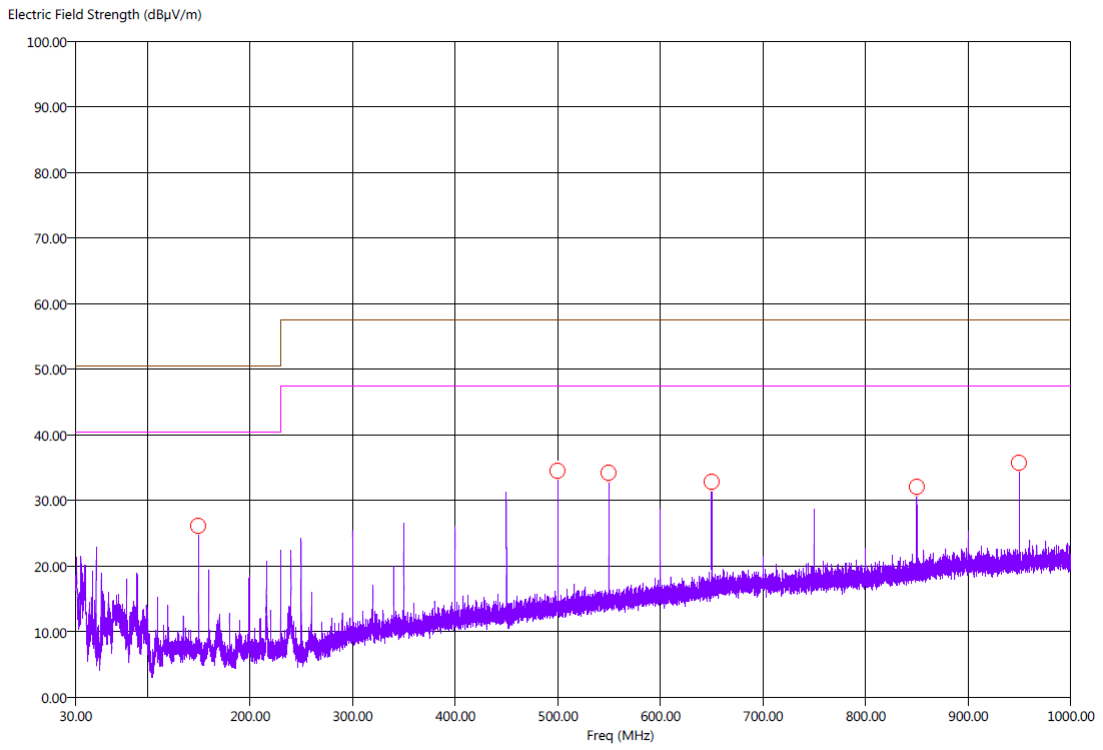
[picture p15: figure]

Regulatory EMI Test Report | eInfochips Ltd. Confidential | Page 9 of 10

Figure 4: Test Result- Vertical Scan

Regulatory EMI Test Report | eInfochips Ltd. Confidential | Page 10 of 10

2.1.7 Test Result / summary.

AIT1L EUTs are passing CISPR-22 Class-A with >18dB margin and Class-B with >8dB margin.

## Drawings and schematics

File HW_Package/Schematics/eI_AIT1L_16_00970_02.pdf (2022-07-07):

PCB Rev. | Sch Rev. | Date

# AIT1L

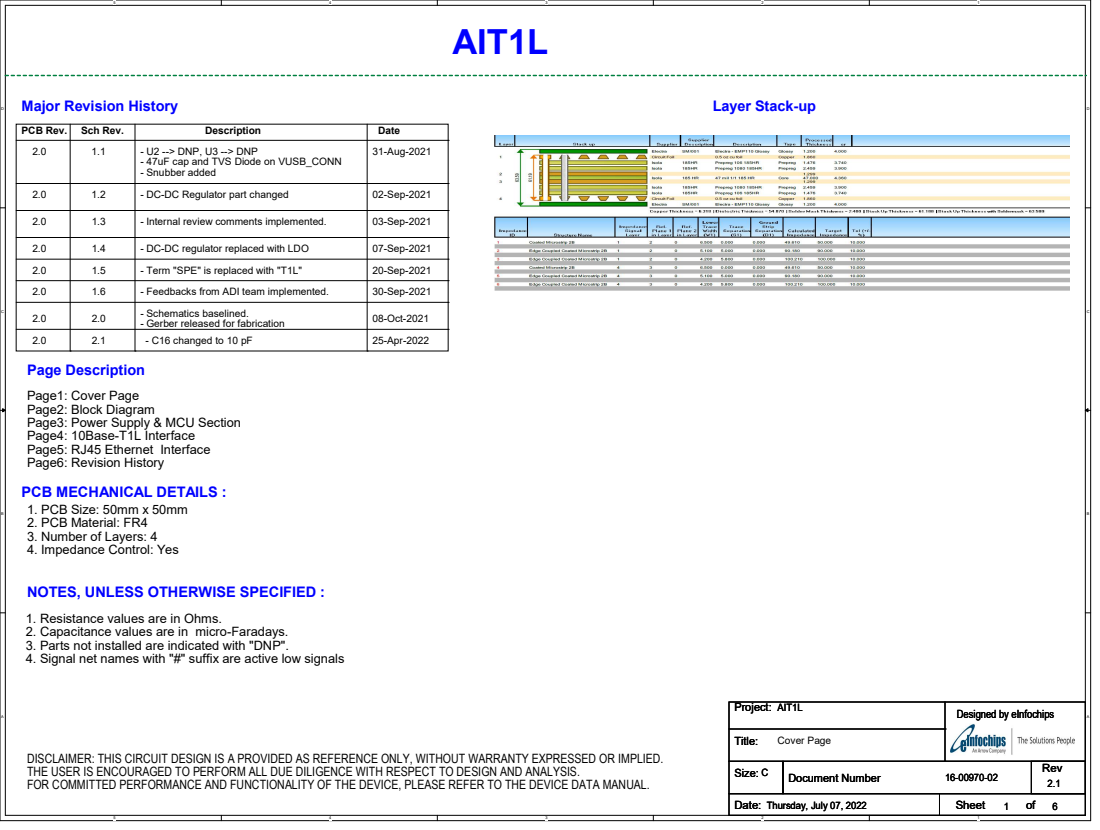
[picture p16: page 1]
Cover Page; Description; 31-Aug-2021; - DC-DC Regulator part changed; 02-Sep-2021; 03-Sep-2021 1.3; - Internal review comments implemented.; 07-Sep-2021 1.4; - DC-DC regulator replaced with LDO; 20-Sep-2021 1.5; - Term "SPE" is replaced with "T1L"; 30-Sep-2021 1.6; - Feedbacks from ADI team implemented.; - Schematics baselined.; - Gerber released for fabrication 2.0; 08-Oct-2021 2.0; 25-Apr-2022 2.1; - C16 changed to 10 pF; Title:; Size:; Project:; Rev; Date:; Document Number; Sheet; AIT1L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

Major Revision History

Layer Stack-up

- U2 --> DNP, U3 --> DNP
- 47uF cap and TVS Diode on VUSB_CONN
- Snubber added

Page Description
Page1: Cover Page
Page2: Block Diagram
Page3: Power Supply & MCU Section
Page4: 10Base-T1L Interface
Page5: RJ45 Ethernet Interface
Page6: Revision History
PCB MECHANICAL DETAILS :
1. PCB Size: 50mm x 50mm
2. PCB Material: FR4
3. Number of Layers: 4
4. Impedance Control: Yes

NOTES, UNLESS OTHERWISE SPECIFIED :
1. Resistance values are in Ohms.
2. Capacitance values are in micro-Faradays.
3. Parts not installed are indicated with "DNP".
4. Signal net names with "#" suffix are active low signals

Designed by eInfochips

DISCLAIMER: THIS CIRCUIT DESIGN IS A PROVIDED AS REFERENCE ONLY, WITHOUT WARRANTY EXPRESSED OR IMPLIED.
THE USER IS ENCOURAGED TO PERFORM ALL DUE DILIGENCE WITH RESPECT TO DESIGN AND ANALYSIS.
FOR COMMITTED PERFORMANCE AND FUNCTIONALITY OF THE DEVICE, PLEASE REFER TO THE DEVICE DATA MANUAL.

# Block Diagram

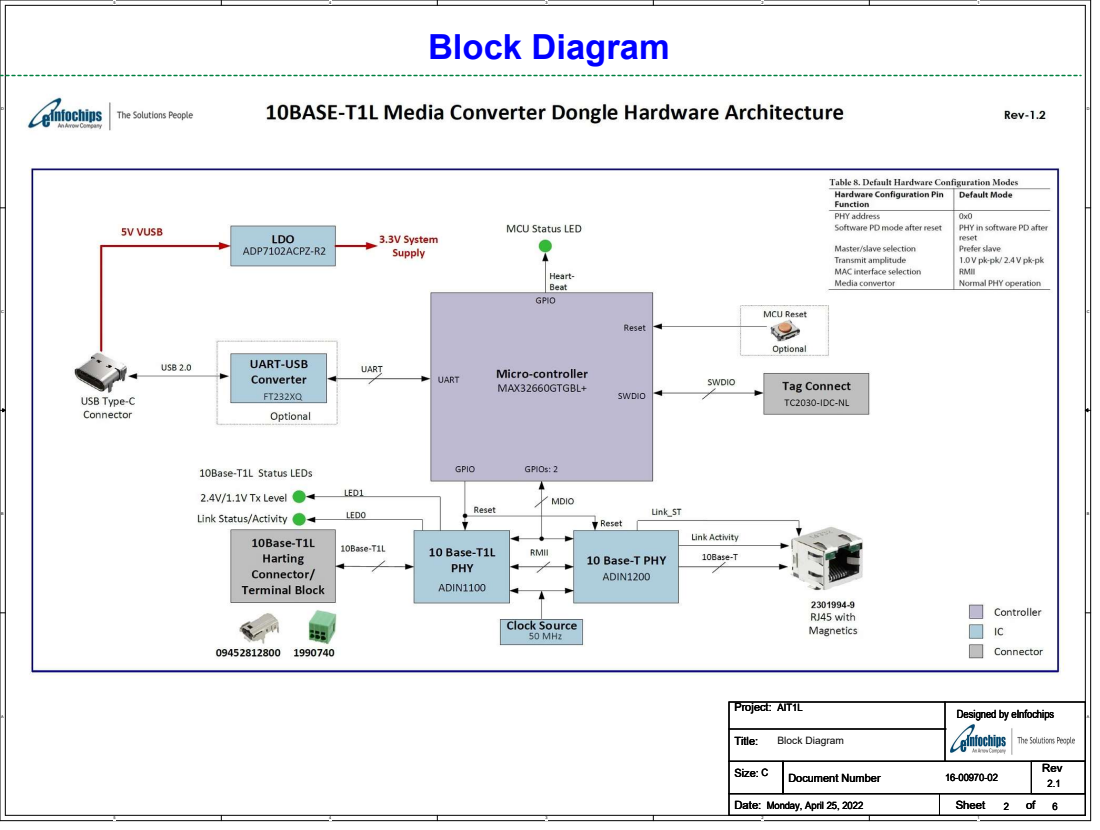
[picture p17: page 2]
Block Diagram; Title:; Size:; Project:; Rev; Document Number; AIT1L; Monday, April 25, 2022

Designed by eInfochips

# Power Supply & MCU Section

# USB Type-C Connector

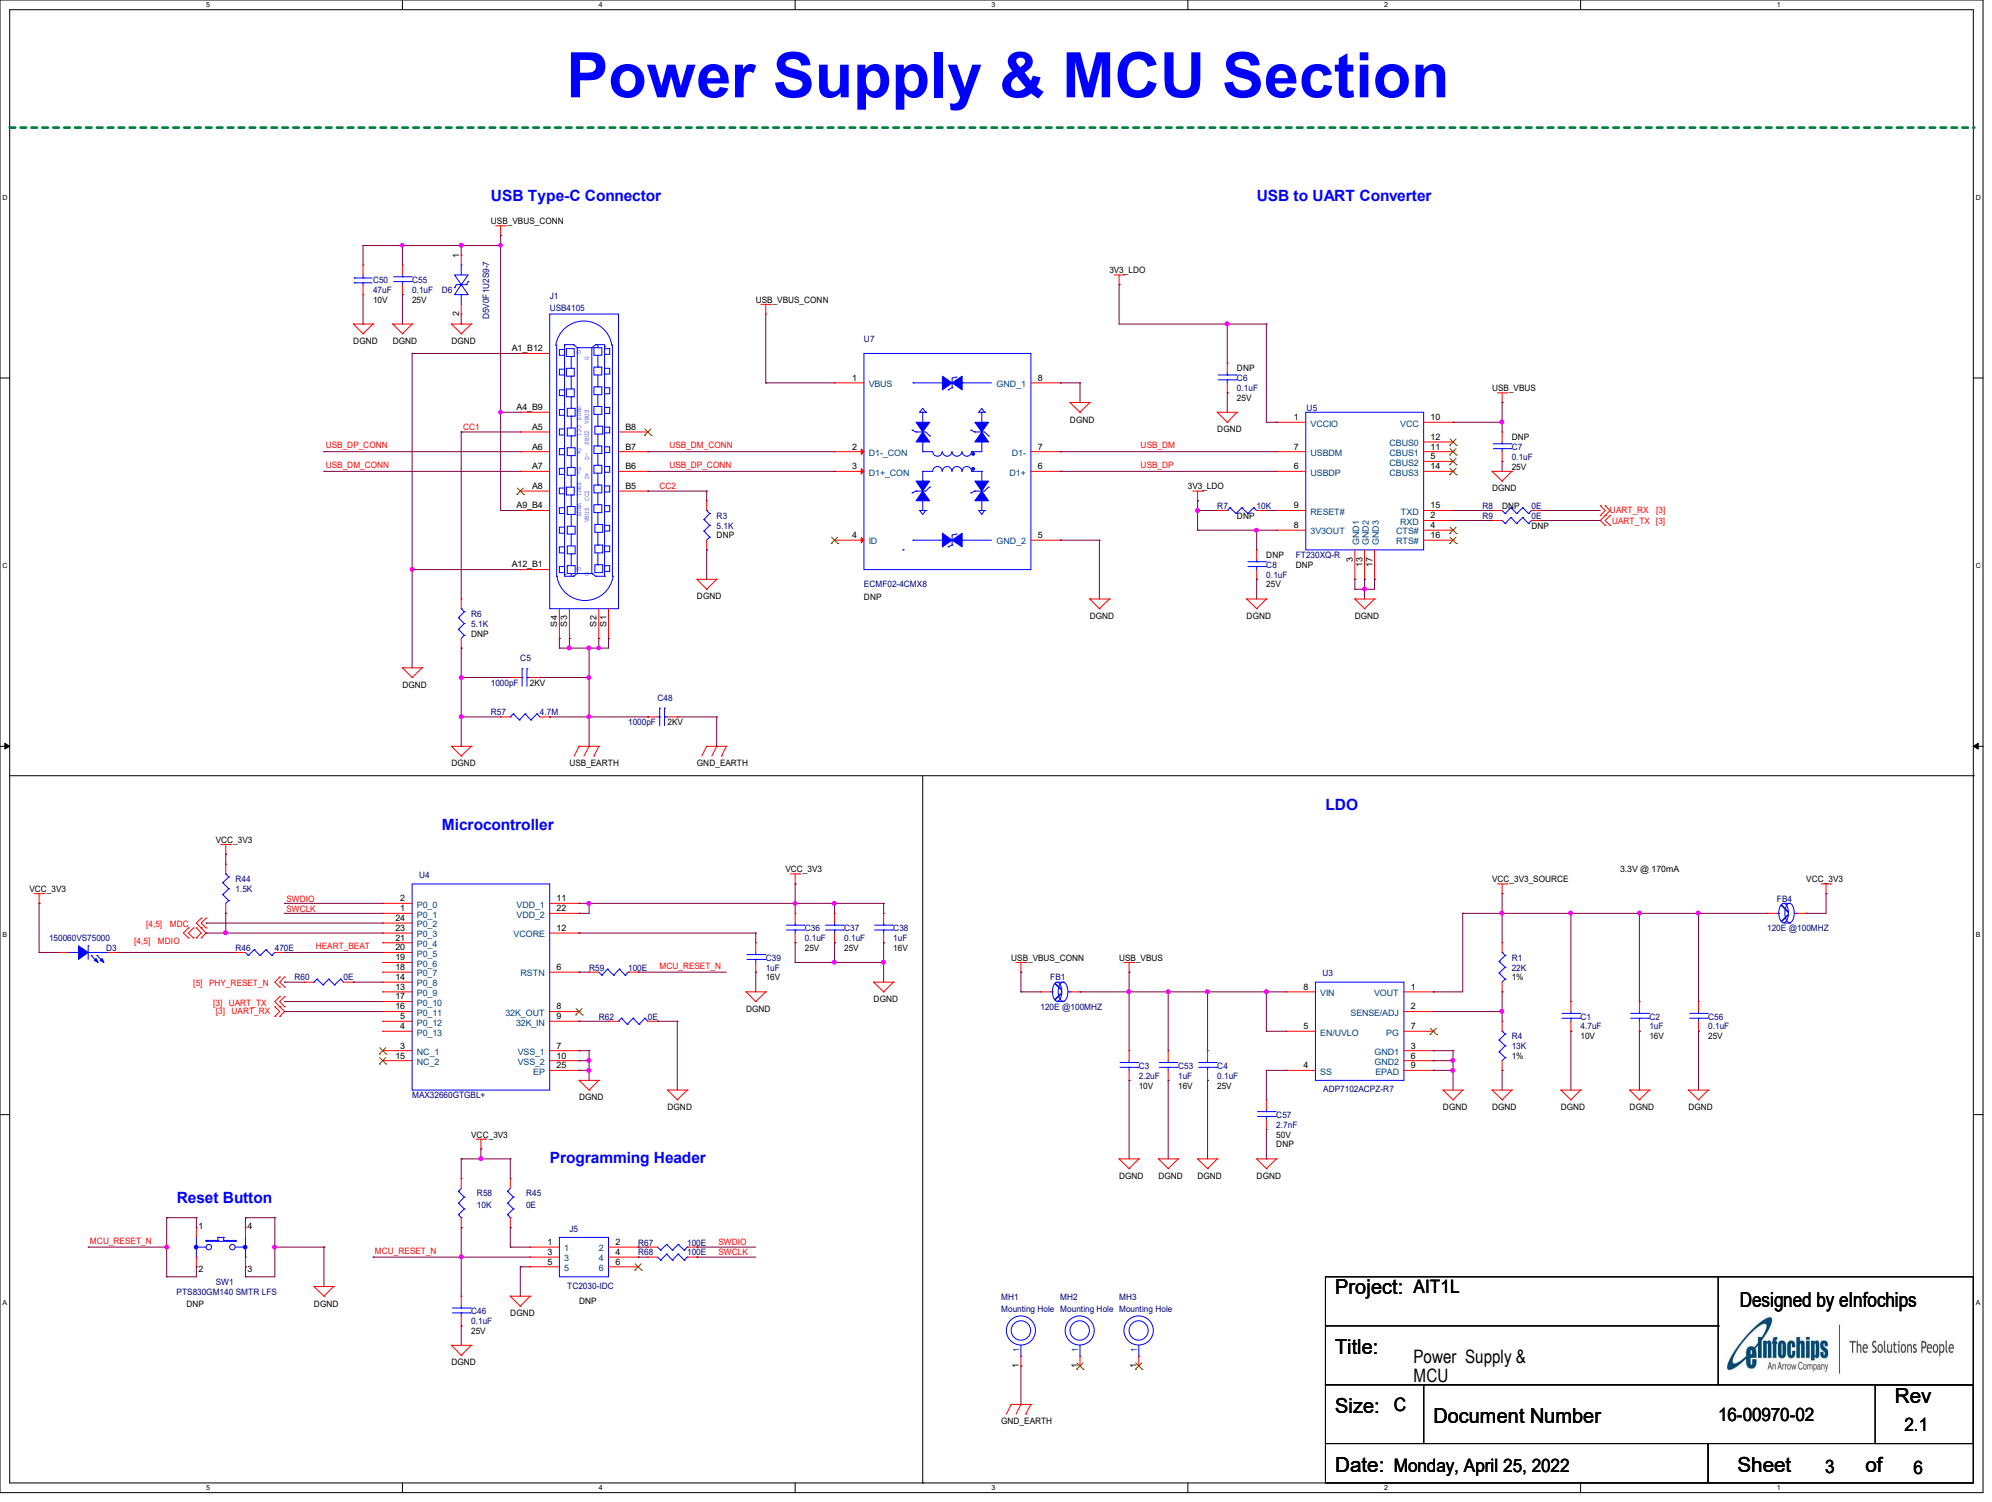
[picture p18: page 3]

USB to UART Converter

G VBUS CC1 D+ D- SBU1 VBUS G D- SBU2 G CC2 VBUS G VBUS D+

# 10Base-T1L Ethernet

# HW Boot Straping

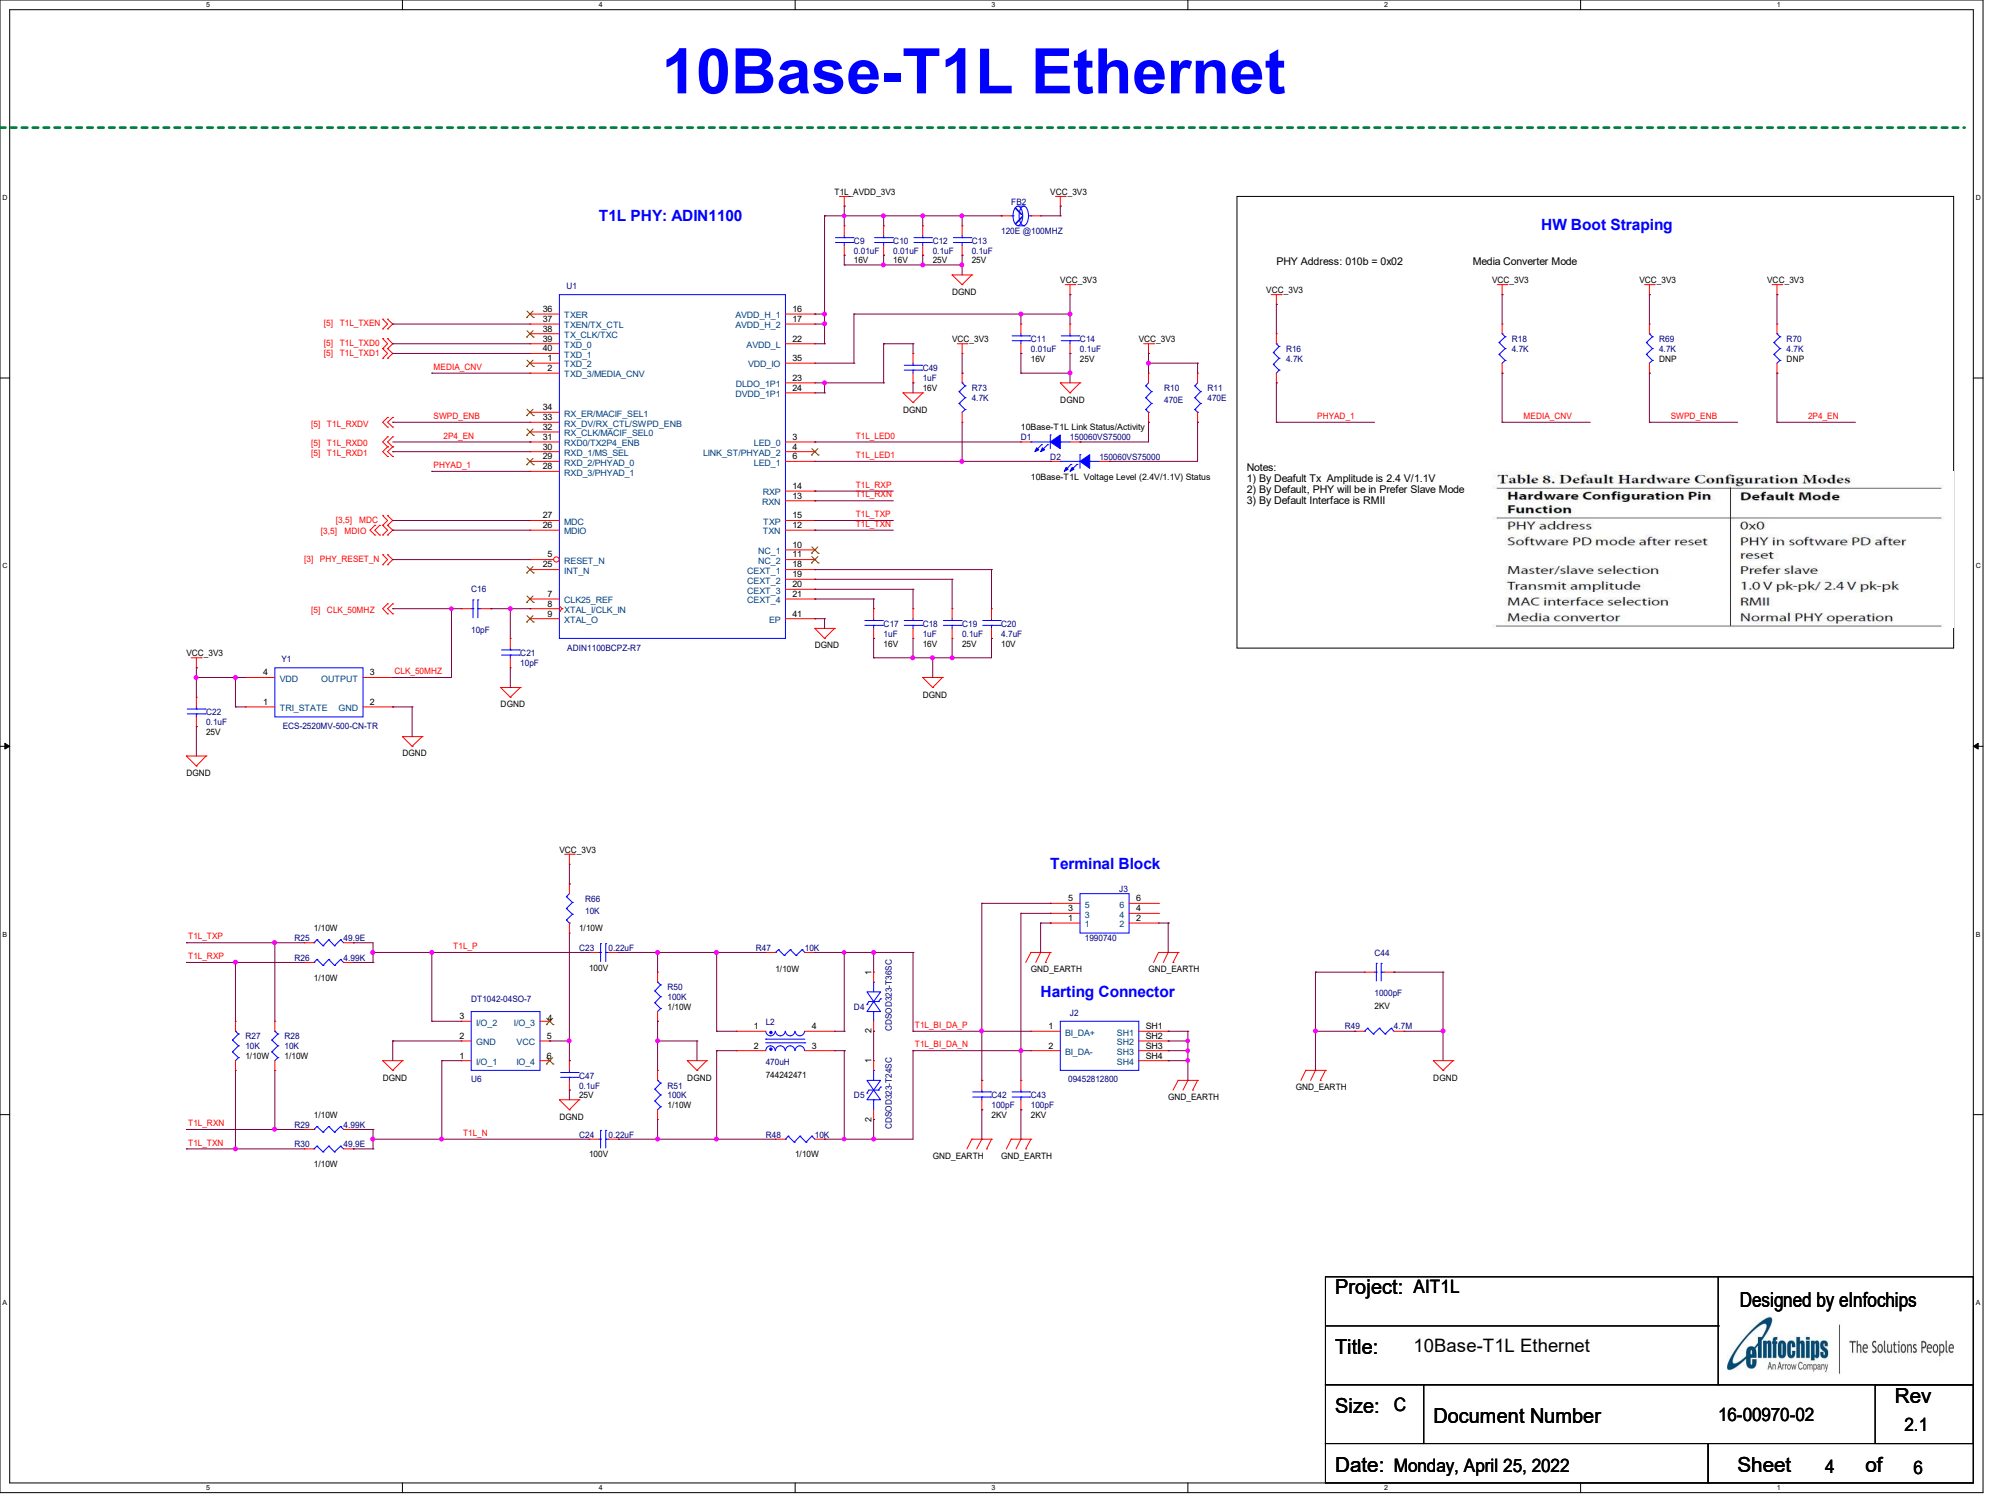
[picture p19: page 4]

10Base-T1L Voltage Level (2.4V/1.1V) Status DGND

Notes:
1) By Deafult Tx Amplitude is 2.4 V/1.1V
2) By Default, PHY will be in Prefer Slave Mode
3) By Default Interface is RMII

# Ethernet

# Ethernet PHY: ADIN1200

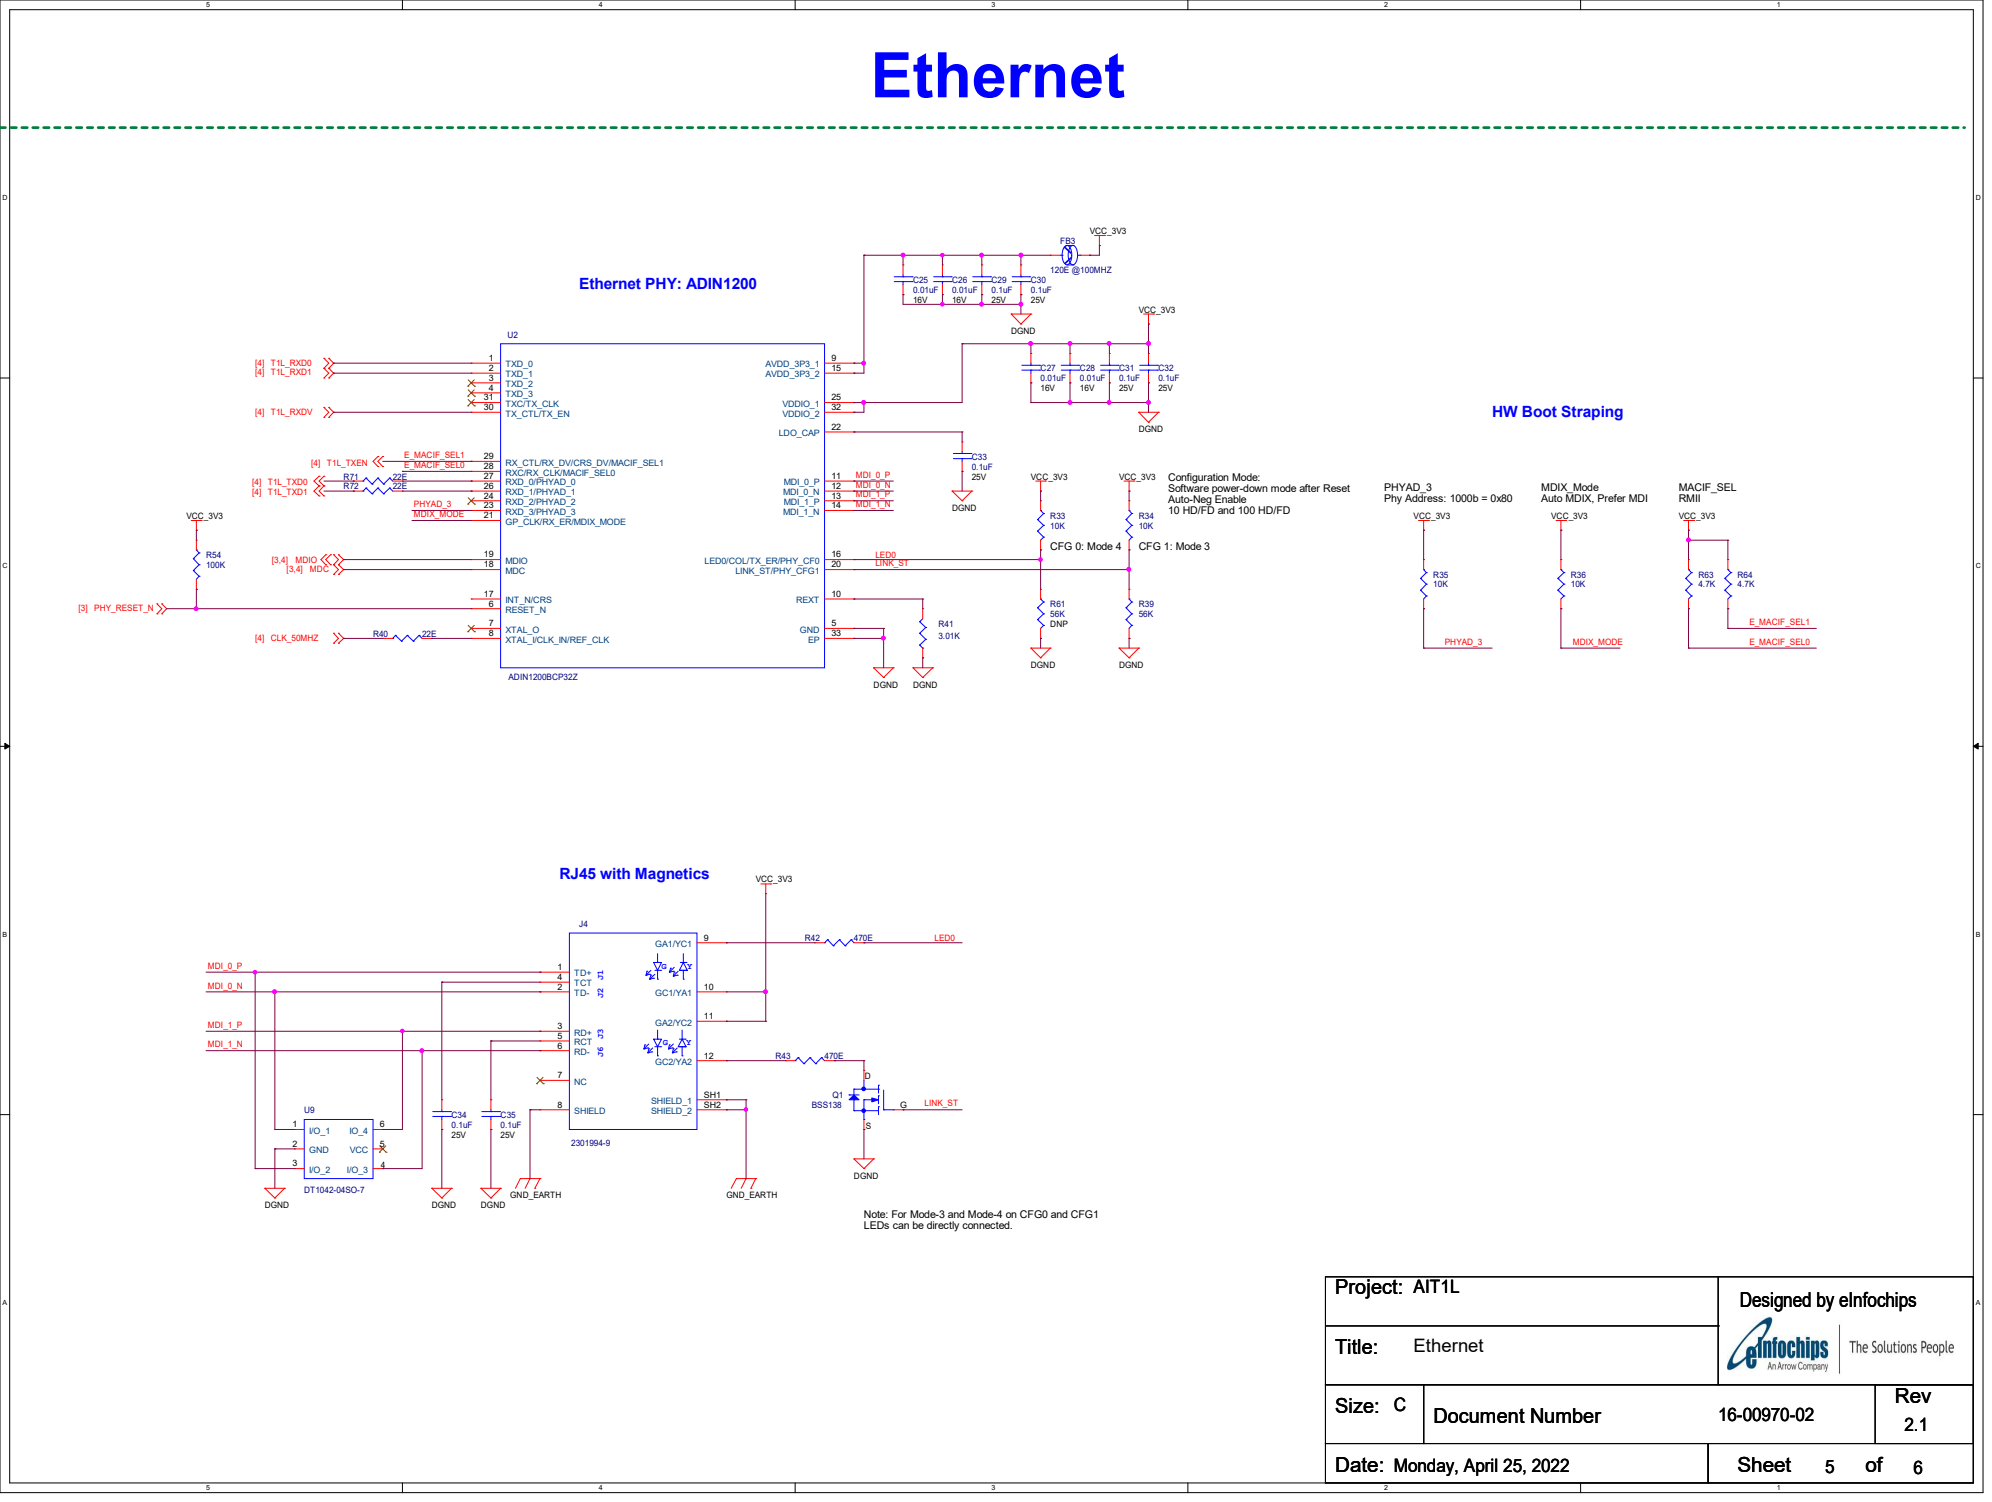
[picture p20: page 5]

Configuration Mode:
Software power-down mode after Reset
Auto-Neg Enable
10 HD/FD and 100 HD/FD

MDIX_Mode
Auto MDIX, Prefer MDI

Note: For Mode-3 and Mode-4 on CFG0 and CFG1
LEDs can be directly connected.

D D

C C

B B

A A

# Revision History

# Revision History

0.3 07-Jun-2021 | Series resistors on RMII removed. - Single Reset for ADIN1100 and ADIN1200. - ADIN1100 and ADIN1200 Link_Status signals are removed from MCU | | eInfochips
0.4 0.5 - Tag connect part changed to TC2030-IDC | - 100 ohm series resistors added on SWD lines - Separate Earth GND for USB | 15-Jun-2021 18-Jun-2021 | eInfochips eInfochips
0.6 - VCCIO of U3 is connected with 3V3_LDO. VCC_3V3 provision is removed. | | 22-Jun-2021 | eInfochips
0.7 | Schematic update after customer review: - R17 deleted on SWPD_EN line; Q2 deleted on ADIN1200 LED0 line; - Two TVS diode in series in between 10Base-T1L signals. | 24-Jun-2021 | eInfochips

# Description

1.4 - DC-DC regulator is changed with LDO ADP7102ACPZ-R7 | | 07-Sep-2021 | eInfochips
1.5 | - Term "SPE" is replaced with "T1L" | 20-Sep-2021 | eInfochips
1.6 | Customer's suggestion implemented: - Refdes change: U4-->U1; U7-->U2; U11-->U3; U10-->U4; U3-->U5; U2-->U7 - 4.7K added on ADIN1100 LED_1 pin | 30-Sep-2021 | eInfochips
2.0 | - Schematics is baselined; Gerber released for fabrication; | 08-Oct-2021 | eInfochips
PCB Rev. | Sch. Rev. | Author

# 03-Sep-2021

# Date 0.1 26-May-2021 Initial Draft version created

# eInfochips

# eInfochips

0.2

# MCU XTAL is removed; FBs are added on AVDD supplies

# eInfochips

1.0 03-Jul-2021 | Schematics baslined; Gerber released for fabrication; | | eInfochips
| 1.1 | Initial Beta draft: - U3 (FT232XQ) --> DNP; U2 (ECMF02-4CMX8) --> DNP - 47uF and TVS diode D5V0F1U2S9-7 cap added on VUSB_CONN - 0E series resistor added on T1L_TXD0 and T1L_TXD1 - RJ45 part changed to 2301994-9 - Snubber added on SW node of Buck-Regulator | 31-Aug-2021 | eInfochips
| 1.2 | - Buck Regulator is changed to LTC3103IMSE#PBF | 02-Sep-2021 | eInfochips

0.8

Provision added on SWPD_EN and 2P4_ENB pins;

# R50 and R51 moved in between C23 and C24 and CMC

# 28-Jun-2021

2.0

# Internal review comments implemented: - Discrete components of U3 are DNP

- Series resistors on T1L_TXD0 and T1L_TXD1 are moved to source side.
- 0.1uF cap added on VUSB_CONN near connector.
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

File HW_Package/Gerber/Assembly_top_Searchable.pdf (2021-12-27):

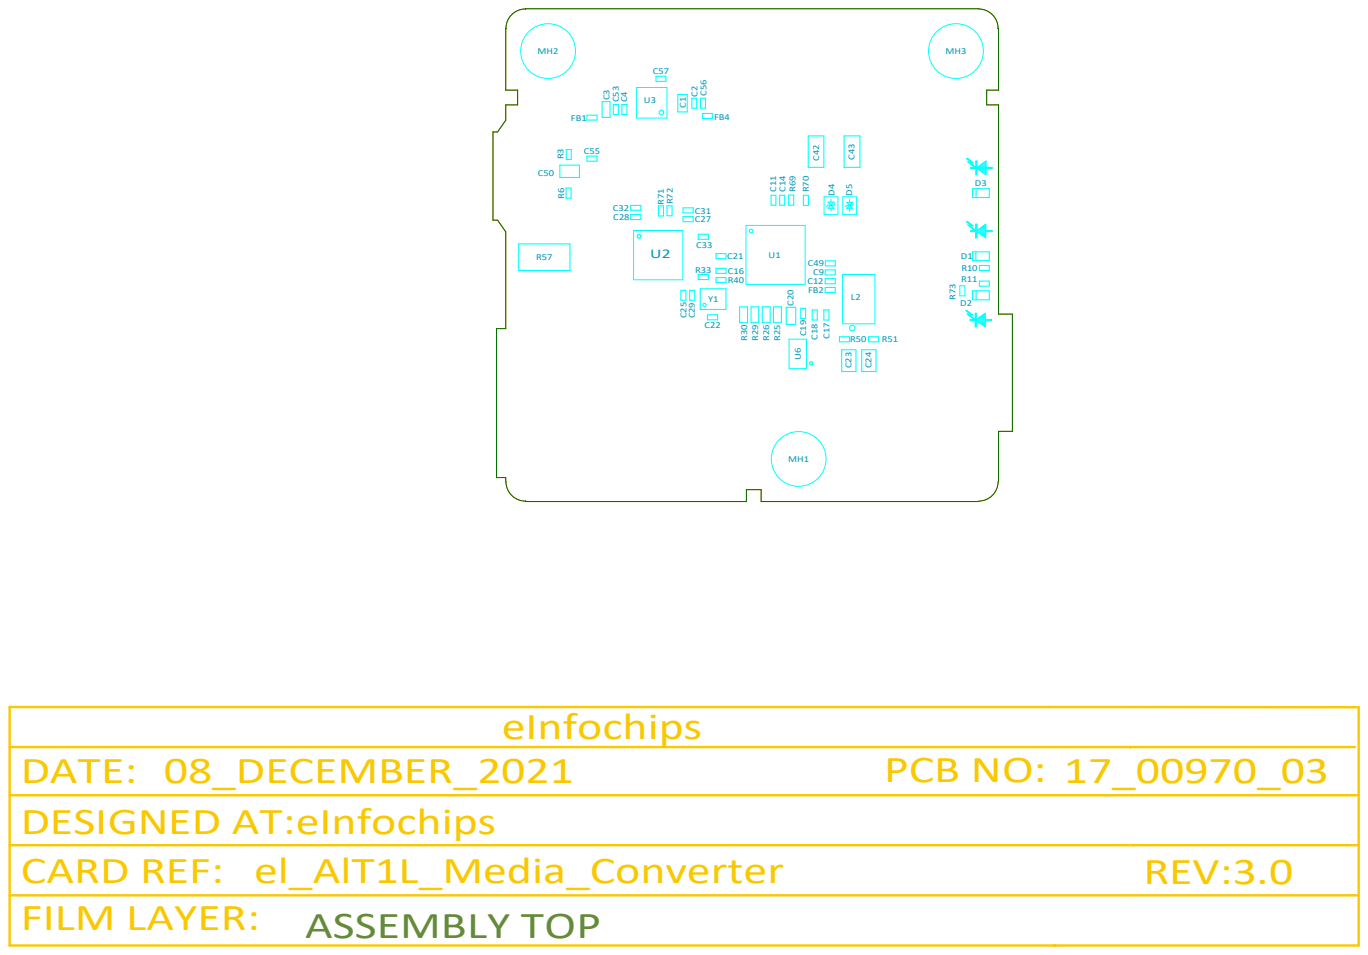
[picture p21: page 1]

DATE:
DESIGNED AT:eInfochips
CARD REF:
FILM LAYER: ASSEMBLY TOP

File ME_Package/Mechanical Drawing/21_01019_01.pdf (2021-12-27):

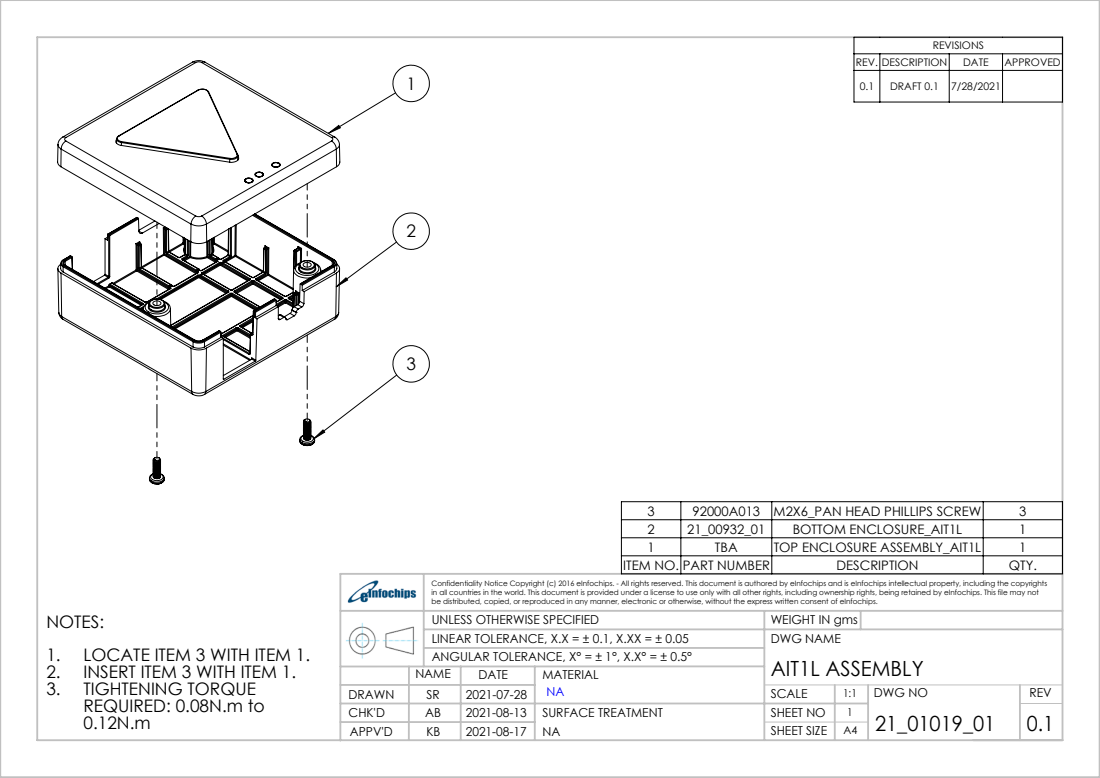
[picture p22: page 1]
ANGULAR TOLERANCE, X° = ± 1°, X.X° = ± 0.5°

REVISIONS

REV. DESCRIPTION | | DATE | APPROVED
0.1 | DRAFT 0.1 | 7/28/2021

3 | 92000A013 | M2X6_PAN HEAD PHILLIPS SCREW | 3
2 | 21_00932_01 | BOTTOM ENCLOSURE_AIT1L | 1
1 | TBA | TOP ENCLOSURE ASSEMBLY_AIT1L | 1
ITEM NO. PART NUMBER | | DESCRIPTION | QTY.

Confidentiality Notice Copyright (c) 2016 eInfochips. - All rights reserved. This document is authored by eInfochips and is eInfochips intellectual property, including the copyrights in all countries in the world. This document is provided under a license to use only with all other rights, including ownership rights, being retained by eInfochips. This file may not be distributed, copied, or reproduced in any manner, electronic or otherwise, without the express written consent of eInfochips.

NOTES:
1. LOCATE ITEM 3 WITH ITEM 1.
2. INSERT ITEM 3 WITH ITEM 1.
3. TIGHTENING TORQUE
REQUIRED: 0.08N.m to

UNLESS OTHERWISE SPECIFIED | WEIGHT IN gms
LINEAR TOLERANCE, X.X = ± 0.1, X.XX = ± 0.05 | DWG NAME AIT1L ASSEMBLY

NAME | DATE | MATERIAL NA

DRAWN | SR | 2021-07-28 | | SCALE | 1:1 | DWG NO | REV
CHK'D | AB | 2021-08-13 | SURFACE TREATMENT NA | SHEET SIZE | A4 1 | 21_01019_01 SHEET NO | 0.1
APPV'D | KB | 2021-08-17

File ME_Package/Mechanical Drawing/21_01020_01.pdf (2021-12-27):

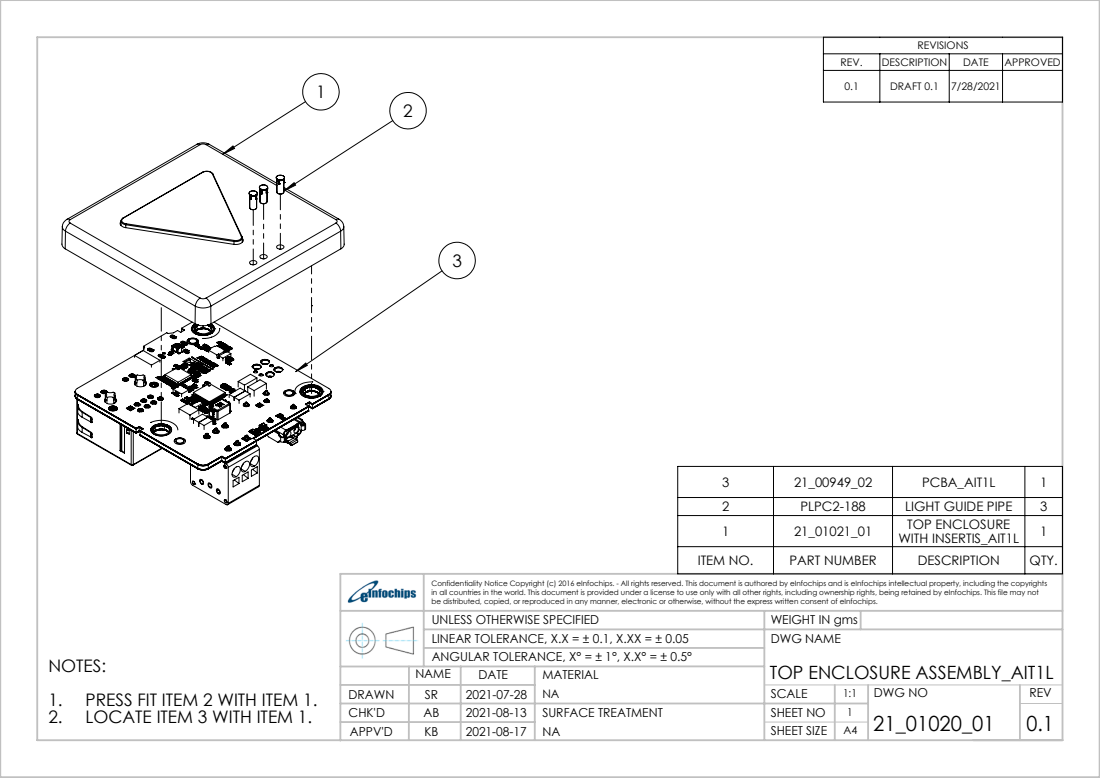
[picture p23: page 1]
ANGULAR TOLERANCE, X° = ± 1°, X.X° = ± 0.5°

REVISIONS

REV. | DESCRIPTION | DATE | APPROVED
0.1 | DRAFT 0.1 | 7/28/2021

3 | 21_00949_02 | PCBA_AIT1L | 1
2 | PLPC2-188 | LIGHT GUIDE PIPE | 3
1 | 21_01021_01 | TOP ENCLOSURE WITH INSERTIS_AIT1L | 1

ITEM NO. | PART NUMBER | DESCRIPTION | QTY.

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

UNLESS OTHERWISE SPECIFIED | WEIGHT IN gms
LINEAR TOLERANCE, X.X = ± 0.1, X.XX = ± 0.05 | DWG NAME TOP ENCLOSURE ASSEMBLY_AIT1L

NOTES:
1. PRESS FIT ITEM 2 WITH ITEM 1.
2. LOCATE ITEM 3 WITH ITEM 1.

NAME | DATE | MATERIAL NA

DRAWN | SR | 2021-07-28 | | SCALE | 1:1 | DWG NO 21_01020_01 | REV
CHK'D | AB | 2021-08-13 | SURFACE TREATMENT NA | SHEET NO | 1 | | 0.1
APPV'D | KB | 2021-08-17 | | SHEET SIZE | A4

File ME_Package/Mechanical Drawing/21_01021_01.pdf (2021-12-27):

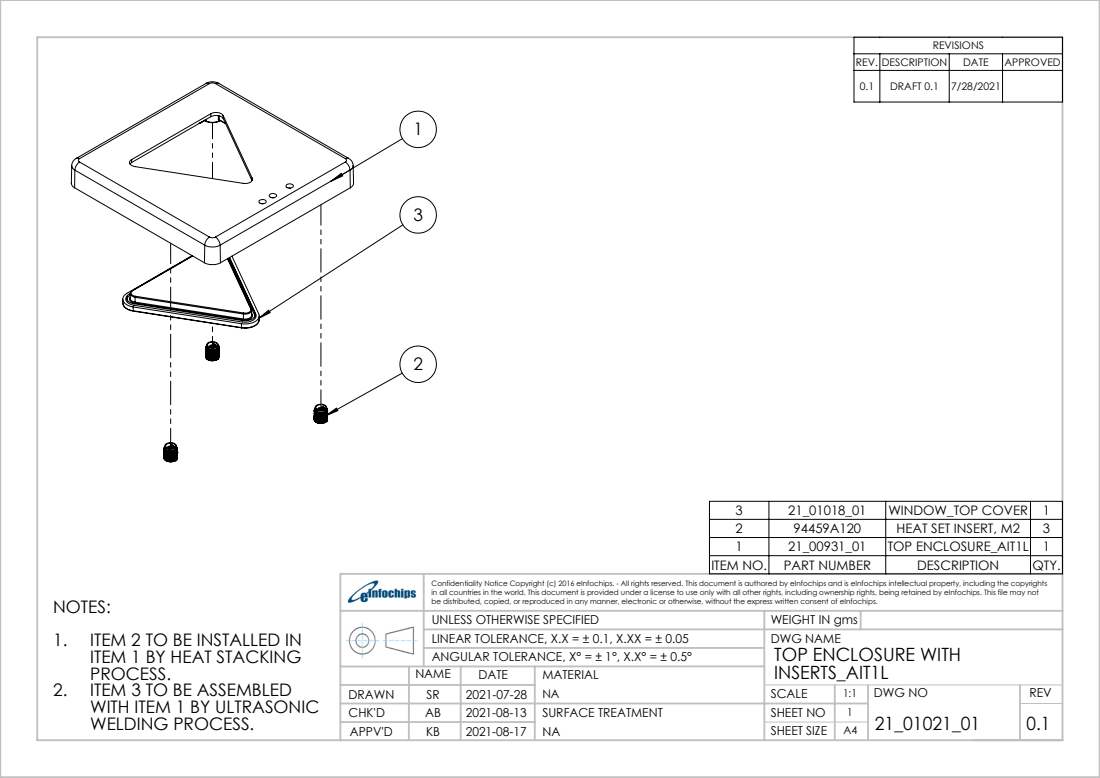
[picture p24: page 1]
ANGULAR TOLERANCE, X° = ± 1°, X.X° = ± 0.5°

REVISIONS

REV. DESCRIPTION | | DATE | APPROVED
0.1 | DRAFT 0.1 | 7/28/2021

3 | 21_01018_01 | WINDOW_TOP COVER | 1
2 | 94459A120 | HEAT SET INSERT, M2 | 3
1 | 21_00931_01 | TOP ENCLOSURE_AIT1L | 1
ITEM NO. | PART NUMBER | DESCRIPTION | QTY.

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

NOTES:
1. ITEM 2 TO BE INSTALLED IN
ITEM 1 BY HEAT STACKING
PROCESS.
2. ITEM 3 TO BE ASSEMBLED
WITH ITEM 1 BY ULTRASONIC
WELDING PROCESS.

UNLESS OTHERWISE SPECIFIED | WEIGHT IN gms
LINEAR TOLERANCE, X.X = ± 0.1, X.XX = ± 0.05 | DWG NAME TOP ENCLOSURE WITH INSERTS_AIT1L

NAME | DATE | MATERIAL NA

DRAWN | SR | 2021-07-28 | | SCALE | 1:1 | DWG NO 21_01021_01 | REV
CHK'D | AB | 2021-08-13 | SURFACE TREATMENT NA | SHEET NO | 1 | | 0.1
APPV'D | KB | 2021-08-17 | | SHEET SIZE | A4

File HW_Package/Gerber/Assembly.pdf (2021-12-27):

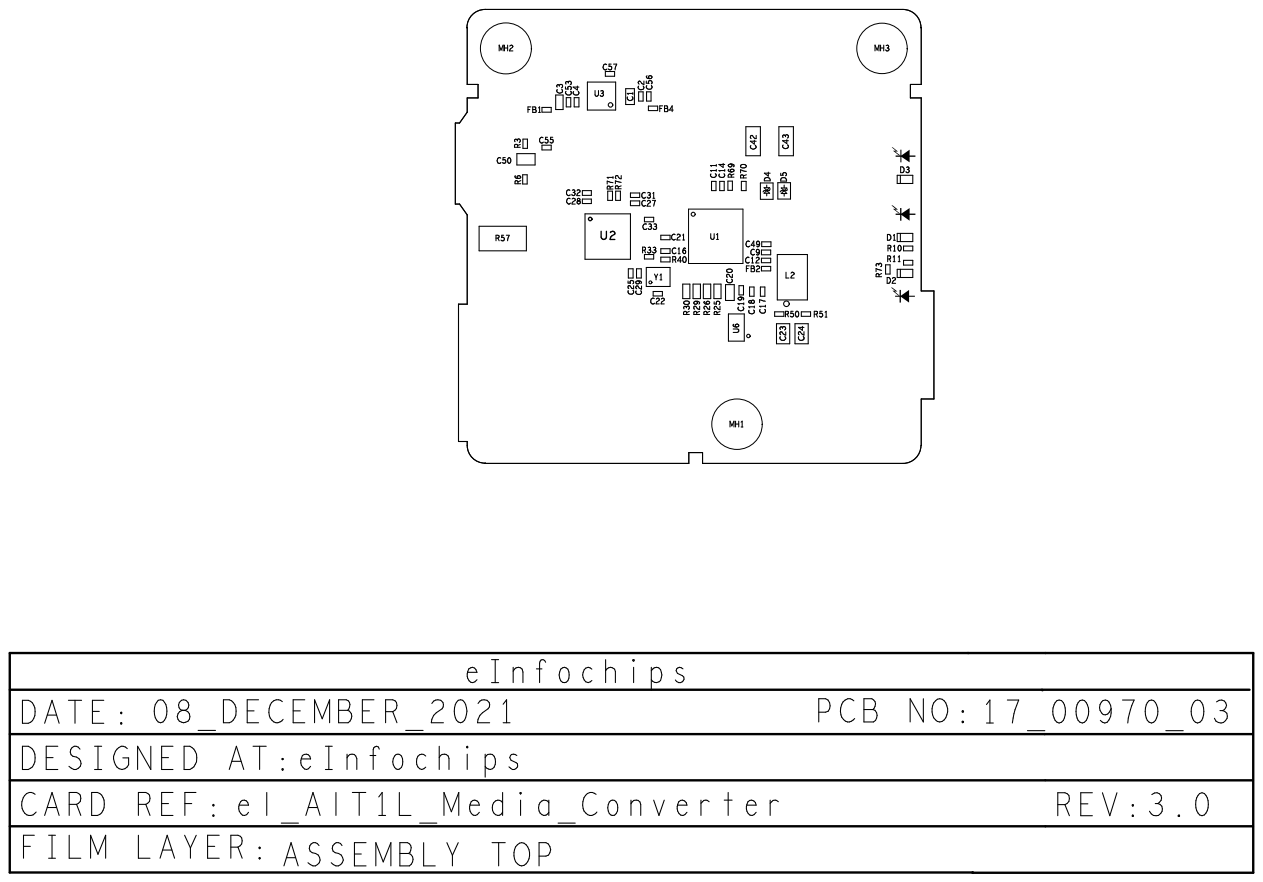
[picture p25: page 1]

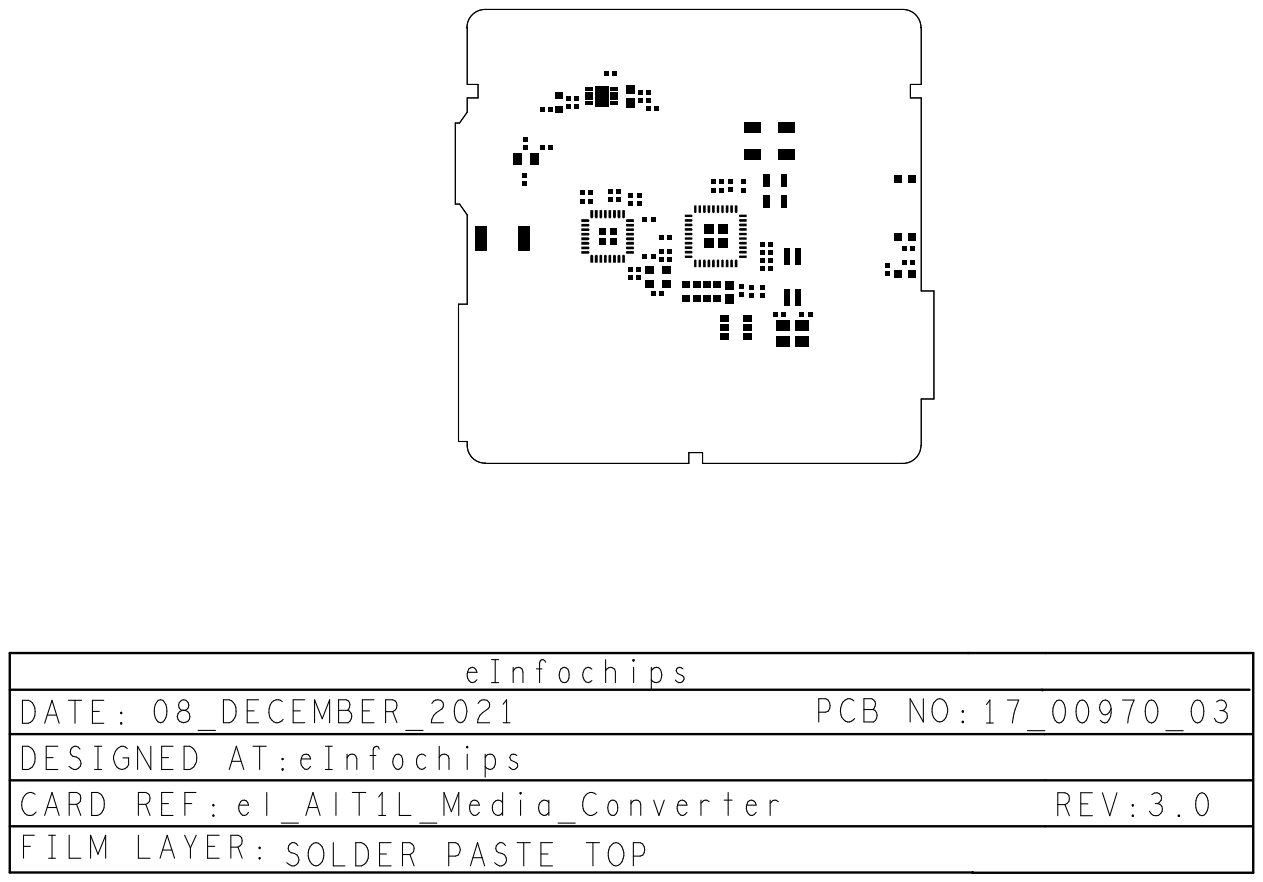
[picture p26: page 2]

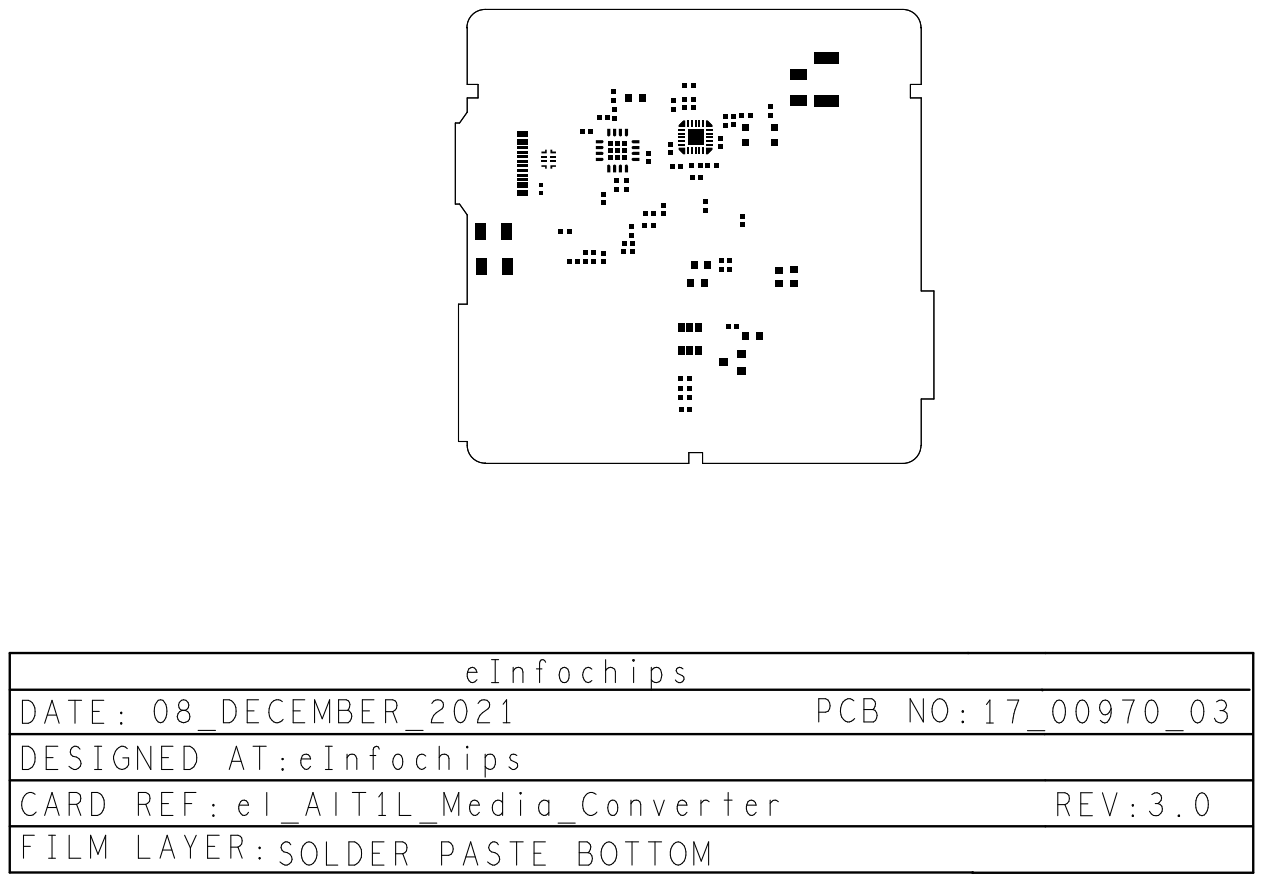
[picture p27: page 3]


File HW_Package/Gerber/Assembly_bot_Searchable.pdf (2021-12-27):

J5 | R8 R46 R48 R47 | C35 R16
J2 | J1


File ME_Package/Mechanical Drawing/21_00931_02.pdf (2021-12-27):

3X 2.00 THRU; SECTION A-A; SCALE 1 : 1; SECTION B-B SCALE 1 : 1; ANGULAR TOLERANCE, X° = ± 1°, X.X° = ± 0.5°

NOTES:
1. ALL DIMENSIONS ARE IN MM.
2. MATERIAL: ABS(RTP 601 FR A)
3. SURFACE FINISH: MATTE
4. COLOUR: BLUE(PANTONE 2144C)
5. PARTS SHOULD BE FREE FROM BURRS &
SCRATCHES.
6. THERE SHOULD BE NO FLASHES.
7. UNLESS OTHERWISE SPECIFIED, CONSIDER FILLET
8. UNLESS OTHERWISE SPECIFIED, CONSIDER DRAFT
ANGLE TO BE 1 . 9. PLEASE REFER 3D MODEL FOR MORE DETAILS.

Confidentiality Notice Copyright (c) 2016 eInfochips. - All rights reserved. This document is authored by eInfochips and is eInfochips intellectual property, including the copyrights in all countries in the world. This document is provided under a license to use only with all other rights, including ownership rights, being retained by eInfochips. This file may not be distributed, copied, or reproduced in any manner, electronic or otherwise, without the express written consent of eInfochips.
LINEAR TOLERANCE, X.X = ± 0.1, X.XX = ± 0.05 | DWG NAME TOP ENCLOSURE_AIT1L_REV 2

UNLESS OTHERWISE SPECIFIED | WEIGHT IN gms

NAME | DATE | MATERIAL REFER NOTES

DRAWN | SR | 2021-07-28 | | SCALE | 1:1 | DWG NO | REV
CHK'D | AB | 2021-08-13 | SURFACE TREATMENT REFER NOTES | SHEET NO | 1 A3 | 21_00931_02 SHEET SIZE | 0.1
APPV'D | KB | 2021-08-17

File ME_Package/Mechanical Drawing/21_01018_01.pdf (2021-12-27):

SECTION A-A; DETAIL B SCALE 10 : 1; PLEASE REFER 3D MODEL FOR FURTHER DETAILS.; REFER NOTES; ANGULAR TOLERANCE, X° = ± 1°, X.X° = ± 0.5°

Confidentiality Notice Copyright (c) 2016 eInfochips. - All rights reserved. This document is authored by eInfochips and is eInfochips intellectual property, including the copyrights in all countries in the world. This document is provided under a license to use only with all other rights, including ownership rights, being retained by eInfochips. This file may not be distributed, copied, or reproduced in any manner, electronic or otherwise, without the express written consent of eInfochips.
LINEAR TOLERANCE, X.X = ± 0.1, X.XX = ± 0.05 | DWG NAME WINDOW_TOP COVER

UNLESS OTHERWISE SPECIFIED | WEIGHT IN gms

1. ALL DIMENSIONS ARE IN MM
2. MATERIAL: PC
3. SURFACE FINISH: NA
4. UNLESS OTHERWISE SPECIFIED, DRAFT ANGLE IS 1
5. PART SHOULD BE FREE FROM BURR & SCRATCHES.

NAME | DATE | MATERIAL REFER NOTES

DRAWN | SR | 2021-07-28 | | SCALE | 1:1 | DWG NO | REV
CHK'D | AB | 2021-08-13 | SURFACE TREATMENT | SHEET SIZE | A4 1 | 21_01018_01 SHEET NO | 0.1
APPV'D | KB | 2021-08-17

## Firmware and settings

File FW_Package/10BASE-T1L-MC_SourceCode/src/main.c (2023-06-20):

/**
 * @file        main.c
 * @brief       GPIO Example
 * @details     
 */

/*******************************************************************************
* Copyright (C) Maxim Integrated Products, Inc., All Rights Reserved.
*
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
* Except as contained in this notice, the name of Maxim Integrated 
* Products, Inc. shall not be used except as stated in the Maxim Integrated 
* Products, Inc. Branding Policy.
*
* The mere transfer of this software does not imply any licenses
* of trade secrets, proprietary technology, copyrights, patents,
* trademarks, maskwork rights, or any other form of intellectual
* property whatsoever. Maxim Integrated Products, Inc. retains all 
* ownership rights.
*
******************************************************************************/

/***** Includes *****/
#include <stdio.h>
#include <string.h>
#include "mxc_device.h"
#include "mxc_delay.h"
#include "nvic_table.h"
#include "pb.h"
#include "board.h"
#include "gpio.h"
#include"mdio_gpio.h"
#include"boardsupport.h"
#include"adi_eth_common.h"
#include"adi_phy.h"
#include"adin1100.h"
#include"adin1200.h"
#include "nvic_table.h"
#include "uart.h"
#include "dma.h"


/***** Definitions *****/

#define true				1
#define false				0


/***** Globals *****/

uint8_t phyDevMem[ADI_PHY_DEVICE_SIZE];

adi_phy_DriverConfig_t phyDrvConfig = {
    .addr       = 0,
    .pDevMem    = (void *)phyDevMem,
    .devMemSize = sizeof(phyDevMem),
    .enableIrq  = true,
};

volatile uint32_t lastLinkCheckTime = 0;
volatile bool     irqFired = false;

/* Configuration function for the ADIN1100, it is executed after */
/* reset and initialization, with the ADIN1100 in software powerdown. */

adi_eth_Result_e appPhyConfig(adin1100_DeviceHandle_t hDevice)
{
    adi_eth_Result_e        result = ADI_ETH_SUCCESS;

    /* Any static configuration that needs to be done before the link */
    /* is brought up can be included here.                            */

    /* Advertisement of Tx Mode at 2.4 V pk-pk for ADIN1100 */
    result = adin1100_AnAdvTxMode(hDevice, ADI_PHY_AN_ADV_TX_REQ_2P4V);

    return result;
}

/* Call back function used in Register Call back as per Event*/
void phyCallback(void *pCBParam, uint32_t Event, void *pArg)
{
    irqFired = true;
}

int main(void)
{

	uint32_t                run = 1;
	uint8_t                error;
	char                    strBuffer[250];
 	adi_phy_LinkStatus_e    linkstatus = ADI_PHY_LINK_STATUS_DOWN;
	adi_phy_LinkStatus_e    old1100linkstatus = ADI_PHY_LINK_STATUS_DOWN;
	adi_phy_LinkStatus_e    old1200linkstatus = ADI_PHY_LINK_STATUS_DOWN;
	adi_eth_Result_e        result;
	adin1100_DeviceStruct_t dev;
	adin1100_DeviceHandle_t hDevice = &dev;
	uint16_t               capabilities;
	adi_eth_Result_e		result_1200;


	/****** System Initialization *****/
	error = BSP_InitSystem();
	MXC_Delay(1500000);
	DEBUG_RESULT("BSP_InitSystem", error, ADI_ETH_SUCCESS);


	/****** Driver Init *****/
	/* If both the MCU and the ADIN1100 are reset simultaneously */
	/* using the RESET button on the board, the MCU may start    */
	/* scanning for ADIN1100 devices before the ADIN1100 has     */
	/* powered up. This is worse if PHY address is configured as */
	/* 0 (default configuration of the board).                   */
	phyDrvConfig.addr = 0x02;
	result = adin1100_Init(hDevice, &phyDrvConfig);
	if (ADI_ETH_SUCCESS == result)
	{
		result = adin1100_GetCapabilities(hDevice, &capabilities);
		if (capabilities & (1 << ADI_PHY_CAP_TX_HIGH_LEVEL))
		{
			DEBUG_MESSAGE("10BASE-T1L Supports 2.4V Tx level");
		}
		else
		{
			DEBUG_MESSAGE("10BASE-T1L do not support 2.4V Tx level");
		}

	}
	else
    {
        /* If PHY Initialization fails, blink Heart beat LED for 80% duty cycle  */
        while(run)
        {
            BSP_HeartBeat_BLINK();
            result = adin1100_Init(hDevice, &phyDrvConfig);
            if (ADI_ETH_SUCCESS == result)
            {
                result = adin1100_GetCapabilities(hDevice, &capabilities);
                if (capabilities & (1 << ADI_PHY_CAP_TX_HIGH_LEVEL))
                {
                    DEBUG_MESSAGE("10BASE-T1L Supports 2.4V Tx level");
                }
                else
                {
                    DEBUG_MESSAGE("10BASE-T1L do not support 2.4V Tx level");
                }

                BSP_HeartBeat();
                break;
            }
        }
    }



	/* Device configuration, performed while the device is in software power down. */
	result = appPhyConfig(hDevice);
	DEBUG_RESULT("appPhyConfig", result, ADI_ETH_SUCCESS);

#ifndef MDIO_GPIO
	/* Register callback for selected events. */
	result = adin1100_RegisterCallback(hDevice, phyCallback, ADI_PHY_EVT_HW_RESET | ADI_PHY_EVT_LINK_STAT_CHANGE);
	DEBUG_RESULT("adin1100_RegisterCallback", result, ADI_ETH_SUCCESS);
#endif

	/* Exit software power down and attempt to bring up the link. */
	result = adin1100_ExitSoftwarePowerdown(hDevice);
	DEBUG_RESULT("adin1100_ExitSoftwarePowerdown", result, ADI_ETH_SUCCESS);

	/* Check the link Status, though the link may not be up at this point */
	result = adin1100_GetLinkStatus(hDevice, &linkstatus);
	DEBUG_RESULT("adin1100_GetLinkStatus", result, ADI_ETH_SUCCESS);

	/* ADIN1200 Configuration */
	result_1200 = adin1200_config();
	if (ADI_ETH_SUCCESS != result_1200)
	{
	/* If PHY Configuration fails, blink MCU Heart Beat LED for 80% duty cycle  */
		while(run)
		{
			BSP_HeartBeat_BLINK();
			result_1200 = adin1200_config();
			if(ADI_ETH_SUCCESS == result_1200)
			{
			    BSP_HeartBeat();
			    break;
			}
		}
	}


	/* Check the Link Status of ADIN1100 after the setup */
	while (run)
	{
		result = adin1100_GetLinkStatus(hDevice, &linkstatus);
		if (result == ADI_ETH_COMM_ERROR)
		{
			//DEBUG_MESSAGE("MDIO communication error");
			printf("MDIO communication error");
		}
		else
		{
			if (result == ADI_ETH_SUCCESS)
			{
				if (old1100linkstatus != linkstatus)
				{
					switch (linkstatus)
					{
						case ADI_PHY_LINK_STATUS_UP:
							strcpy(strBuffer,"10BASE-T1L Link Up");
							break;

						case ADI_PHY_LINK_STATUS_DOWN:
							strcpy(strBuffer, "10BASE-T1L Link Down");
							break;

						default:
							break;
							DEBUG_RESULT("Invalid link status", 0, 1);
					}
					DEBUG_MESSAGE(strBuffer);
				}

				/* Updates the old link status every time with new link */
				old1100linkstatus = linkstatus;
			}
		}

		/* Get the Link Status of adin1200 after the setup */
		result = adin1200_GetLinkStatus(&linkstatus);
		if (old1200linkstatus != linkstatus)
		{
			switch (linkstatus)
			{
				case ADI_PHY_LINK_STATUS_DOWN:
					strcpy(strBuffer, "Ethernet Link Down");
					break;
				case ADI_PHY_LINK_STATUS_UP:
					strcpy(strBuffer,"Ethernet Link Up");
					break;
				default:
					break;
					DEBUG_RESULT("Invalid link status", 0, 1);
			}
			DEBUG_MESSAGE(strBuffer);
		}

		/* Every time update the old link status of PHY */
		old1200linkstatus = linkstatus;

		/* HeartBeat LED to show MCU Health */
		BSP_HeartBeat();

	}

	/* Get the UnInit result, if it is success or error */
	result = adin1100_UnInit(hDevice);
    return 0;
}

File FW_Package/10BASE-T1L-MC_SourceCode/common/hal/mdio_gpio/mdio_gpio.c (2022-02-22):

/*
 *---------------------------------------------------------------------------
 *
 * Copyright (c) 2021 Analog Devices, Inc. All Rights Reserved.
 * This software is proprietary <and confidential> to Analog Devices, Inc.
 * and its licensors.By using this software you agree to the terms of the
 * associated Analog Devices Software License Agreement.
 *
 *---------------------------------------------------------------------------
 */

#include <stdint.h>
#include "mdio_gpio.h"
#include <stdbool.h>
#include "gpio.h"

#include "adi_eth_common.h"


#define MMD_ACR_ADDRESS                 (0x0000U)
#define MMD_ACR_DATA 		        (0x4000U)
#define MMD_ACR_DATA_RW_INCREMENT       (0x8000U)
#define MMD_ACR_DATA_WRITE_INCREMENT    (0xC000U)

#define DEVTYPE(a)         (a >> 16)
#define REGADDR(a)         (a & 0xFFFF)
#define true				1
#define false				0

extern mxc_gpio_cfg_t gpio_MDIO;
extern mxc_gpio_cfg_t gpio_MDC;


void delay (void) {;};
/*
 * @brief Sends bits out for the number of clocks
 *
 * @param [in] value
 * @param [in] nbBits
 * @return none
 *
 * @details
 *
 * @sa
 */
static void bitsOut(uint32_t  value, int32_t nbBits)
{
    int32_t i = 0;

    for(i=0; i < nbBits; i++)
    {
        if ((value & (0x80000000u >> i)) != 0)
        {
            BSP_SetPinMDIO(true);
        }
        else
        {
            BSP_SetPinMDIO(false);
        }

       // delay ();
        BSP_SetPinMDC(true);
       // delay ();
        BSP_SetPinMDC(false);
    }
}

/*
 * @brief Read input pin for number of clocks
 *
 * @param [in] value
 * @param [in] nbBits
 * @return none
 *
 * @details
 *
 * @sa
 */
static uint16_t bitsIn (void)
{
    /* Input a value from the MII PHY management interface. */
    unsigned int i,val = 0;

    BSP_SetPinMDC(false);
    //delay ();
    for (i = 0; i < 16; i++)
    {
        val <<= 1;
        BSP_SetPinMDC(true);
       // delay ();
        BSP_SetPinMDC(false);
        //delay ();
        val |= BSP_GetPinMDInput();
    }
    BSP_SetPinMDC(true);
   // delay ();
    BSP_SetPinMDC(false);

   return (val & 0xFFFF);
}

/*
 * @brief MDIO Read Clause 22
 *
 * @param [in] phyAddr - Hardware Phy address
 * @param [in] phyReg - Register address
 * @param [out] phyData - pointer to the data buffer
 * @return error if TA bit is not pulled down by the slave
 *
 * @details
 *
 * @sa
 */
uint32_t mdioGPIORead(uint8_t phyAddr, uint8_t phyReg, uint16_t *phyData )
{
    uint32_t error = 0;
    int32_t i = 0;
    uint8_t tempBuffer[8] = {0};


    uint32_t temp = 0;
    uint16_t dataIn = 0;

    tempBuffer[i++] = 0xff;
    tempBuffer[i++] = 0xff;
    tempBuffer[i++] = 0xff;
    tempBuffer[i++] = 0xff;

    /* ST('01) + OP('10) + PHYAD(4 MSB) */
    tempBuffer[i] = 0x60;
    tempBuffer[i++] |= (phyAddr & 0x1F) >> 1;

    /* PHYAD(1 LSB) + REGADD (4) + 2 TA('00) */
    tempBuffer[i] = (phyAddr & 0x01) << 7 ;
    tempBuffer[i] |= (phyReg & 0x1F) << 2;
    tempBuffer[i++] |= ( 0x03) ;//3
    tempBuffer[i++] = 0xFF;
    tempBuffer[i++] = 0xFF;


    BSP_ChangeMDIPinDir(true);//output
    temp = (tempBuffer[0] << 24) | (tempBuffer[1] <<16) | (tempBuffer[2] << 8) | tempBuffer[3];
    bitsOut(temp, 32);
    temp = (tempBuffer[4] << 24) | (tempBuffer[5] <<16) | (tempBuffer[6] << 8) | tempBuffer[7];
    bitsOut(temp, 15);
    BSP_ChangeMDIPinDir(false);//input
    dataIn = bitsIn();
    *phyData = dataIn;

    return error;
}

/*
 * @brief MDIO Write Clause 22
 *
 * @param [in] phyAddr - Hardware Phy address
 * @param [in] phyReg - Register address
 * @param [out] phyData -  data to write
 * @return none
 *
 * @details
 *
 * @sa
 */
uint32_t mdioGPIOWrite(uint8_t phyAddr, uint8_t phyReg, uint16_t phyData )
{
    int32_t i = 0;
    uint8_t tempBuffer[8] = {0};

    uint32_t temp = 0;
    tempBuffer[i++] = 0xff;
    tempBuffer[i++] = 0xff;
    tempBuffer[i++] = 0xff;
    tempBuffer[i++] = 0xff;

    /*Preamble*/
    /* ST('01) + OP('01) + PHYAD(4 MSB) */
    tempBuffer[i] = 0x50 ;
    tempBuffer[i++] |= (phyAddr & 0x1F) >> 1;

    /* PHYAD(1 LSB) + REGADD (4) + 2 TA('10) */
    tempBuffer[i] = (phyAddr & 0x01) << 7 ;
    tempBuffer[i] |= (phyReg & 0x1F) << 2;
    tempBuffer[i++] |=  0x2 ;

    /* DATA */
    tempBuffer[i++] = phyData >> 8;
    tempBuffer[i++] = phyData & 0xFF;

    BSP_ChangeMDIPinDir(true);//output
    temp = (tempBuffer[0] << 24) | (tempBuffer[1] <<16) | (tempBuffer[2] << 8) | tempBuffer[3];
    bitsOut(temp, 32);

    temp = (tempBuffer[4] << 24) | (tempBuffer[5] <<16) | (tempBuffer[6] << 8) | tempBuffer[7];
    bitsOut(temp, 32);
    BSP_ChangeMDIPinDir(false);//input

  return 0;
}
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

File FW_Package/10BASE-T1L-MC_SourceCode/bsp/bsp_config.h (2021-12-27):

/*
 *---------------------------------------------------------------------------
 *
 * Copyright (c) 2020 Analog Devices, Inc. All Rights Reserved.
 * This software is proprietary to Analog Devices, Inc.
 * and its licensors.By using this software you agree to the terms of the
 * associated Analog Devices Software License Agreement.
 *
 *---------------------------------------------------------------------------
 */

#ifndef _BSP_CFG_H
#define _BSP_CFG_H


/* GPIO MDIO, pins 2,3 as per pin configuration of MAX32660 MCU*/
#define MDIO_PORT_0             MXC_GPIO0
#define MDIO_PIN_3              MXC_GPIO_PIN_3 //Maxim pin 3

#define MDC_PORT_0              MXC_GPIO0
#define MDC_PIN_2              	MXC_GPIO_PIN_2 //Maxim pin 2

#define MXC_HEARTBEAT_PORT		MXC_GPIO0
#define MXC_HEARTBEAT_PIN_5		MXC_GPIO_PIN_5 //Maxim pin 5

#define MXC_RESET_GPIO			MXC_GPIO0
#define MXC_RESET_PIN_8			MXC_GPIO_PIN_8 //Maxim Pin 8

#define SUCCESS 0u
#define FAILURE 1u

#define ON 1u
#define OFF 0u

#define DMA_ON true
#define DMA_OFF false

#endif /* BSP_CFG_H */

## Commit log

2021-12-27 Updated FW_Packages, HW_Packages, ME_Packages and Manuals
    [BOTTOM ENCLOSURE.STEP, EI_AIT1L_BOM_18_00970_02.xlsx, EI_PES_TMP_ProductBOM_AIT1L_Beta.xlsx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]
2022-01-03 Added PCBA Images.
2022-02-10 Updated the User Manual, Quick Start Guide and HW_Package.
    [EI_AIT1L_BOM_18_00970_02.xlsx, EI_AIT1L_BOM_18_00970_03.xlsx]
2022-02-17 Updated the HW Package.
    [eI_AIT1L_16_00970_02.DSN]
2022-02-21 Updated the ADIN1100 Driver with version adin1100_v1.0.0.
2022-05-10 Updated the BOM and Schematics.
    [EI_AIT1L_BOM_18_00970_03.xlsx, eI_AIT1L_16_00970_02.DSN, eI_AIT1L_16_00970_02_1.DSN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]
2022-06-28 Removed files which will not be useful for the End User 1)Packaging Instructions from ME_Package -removed 2)DSN file from Hardware Schematics -removed
    [eI_AIT1L_16_00970_02_1.DSN]
2022-07-07 Added agreement for Hardware Design
    [eI_AIT1L_18_00970_02_01_BOM.xlsx]
2022-11-03 Updated the BOM - Part Number for Harting
    [eI_AIT1L_18_00970_02_01_BOM.xlsx]
2023-06-20 Work around for the ongoing issue which prevents the device from behaving as expected with recently updated SDK. Note: Disabling the Interupts which are not in use by application as a temporary solut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
    [adi_phy.c, adi_phy.h, main.c]
